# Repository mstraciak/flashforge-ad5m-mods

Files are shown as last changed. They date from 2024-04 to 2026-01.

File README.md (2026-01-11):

# flashforge-ad5m-mods

Here are my mods for flashforge adventurer 5m.
1) 3D chameleon files for FF Ad5M
2) Happy Turtle Lettuce Feeder with 3D chameleon board- HTLF for ANY 3D printer! (also on [printables](https://www.printables.com/model/1534632-htlf-with-3d-chameleon-pcb) ) 
3) Simple magnetic mount for LED bar
4) Change origin of the buildplate (X0,Y0) to the front left corner.
5) Extruder housing. If you have broken or just need new housing, try my design. (recomend printing with SLA printer) 
6) Start/end gcode with autoleveling at the begining of the print for orcaslicer 2.0.0.dev (usefull with sending files over wifi)  
7) Connecting ANY usb webcam direct do LCD (not with existing USB port)
8) Web control printer on local web server. (working with stock 2.4.5 firmware) **I highly recommend a better version of my webcontrol from [Andy4Shurr](https://github.com/Andy4Shurr/flashforge-ad5m-mods)**

This and other useful mods for flashforge adventurer 5m/5m pro are [here](https://github.com/g992/flashforge-ad5m-5mpro-research).

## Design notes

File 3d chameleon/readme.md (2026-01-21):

# Files for 3D chameleon on Flashforge Adventurer 5M

## My STL files for using chameleon

**chameleon-*.stl:**\
Print from PETG. part with oled mount print facing down, support only on buildplate.

 Position of switch is in the middle on the left side. 

## Firmware files
All collected firmware files for 3D chameleon. I recommended version MK4.1. Also is here guide to burn firmware.

## Files for servo cutter and for manual cutter

## Filament semi-automatic cutter
cutter for the filament is [here](https://www.printables.com/model/1252462-update-semi-automatic-filament-cutter-for-flashfor)

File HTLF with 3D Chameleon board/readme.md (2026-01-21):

# Files for modified HTLF with 3d chameleon PCB

**Changes in HTLF design (new STL files):**
- The lobe elements are rotated 70 degrees relative to each other. This ensures that only one filament is pressed at a time and the others are loose.
- The PCB holder is supplemented with holes for the 3D chameleon PCB.
- Only the home switch is used. The other switches are not used.

**Changes in firmware:**
- Removed OLED display support (due to ws2812b and home switch support)
- Home switch connected to the connector marked "S LIMIT"
- WS2812B connected to the connector marked "FILAMENT"
- Removed the option to choose a random filament
- Removed the option to select the next filament in the sequence
- Removed "no command" option. Replaced with "home and idle" command
- Removed motor vibration function when selecting filament
- Removed support for other devices
- Option to select extruder feedrate in code (1197,1496,1796,2245). Note: Original 3D chameleon uses feedrate 1500, so the setting for feedrate 1496 can be used).
- After inserting the current filament into the extruder, the lobe elements move to a parking position where they do not press any filament.
- Changed home and unload command: process move (unload-home/home and go to parking position)
**The "guillotine" function for cutting filament using a servo motor is untouched.**

**Planned changes:**
- Code optimization

cutter for the filament is [here](https://www.printables.com/model/1252462-update-semi-automatic-filament-cutter-for-flashfor)

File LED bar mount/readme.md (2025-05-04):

# Magnetic LED mount

Magnetic mount for selfsticking LED bar.
Its suitable for round magnets 5x1mm.

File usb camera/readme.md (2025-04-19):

# flashforge-ad5m-mods

How to connect any usb camera to camera port on LCD:
1) on LCD is camera port as "USB_CAMERA" and mark +5V, N (neative data), P (positive data), GND.
2) make short cable with connector for port on LCD and USB-A female. If you need a connector, buy a 5 pin JST PH 2.0mm female
3) just connect any usb camera to this new usb port and enable it on LCD.
   now you can use camera and usb stick at the same time.
   




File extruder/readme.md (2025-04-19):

# Files for extruder housing.
i try make model of extruder housing for my printer, because original was damaged with unclog tool. THIS MODEL IS UNTESTED, so if anyone send me feedback, i will be glad for that. original back plate should be fit to this.
Always use latest version. Older versions are only for reference and backup.

**Printing info (SLA):**

Printer: Anycubic photon (with mono upgrade from chitu)

Slicer: Chitubox Basic 2.3

Profile: Elegoo Mars 2 Pro, changed exposure time from 2.5s to 1.7s for accuracy

Resin: Creality Standard Resin

Be sure your SLA printer is calibrated for accuracy.

**Assembly notes:**

Use all parts from original extruder include screw for tension.

M3 threads for tension screw and fan must be tapped.

For fan use M3x16 screws with flat head, or use original screw (not needed tapped).

**Update 19.4.2025** - v4 - its fully function and its tested (load/unload filament) successfully, still untested in printing. still need small correction but now it is usable





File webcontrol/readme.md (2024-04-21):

it need apache+php (like xampp), enabled socket module in php.ini. copy files (index.php and ff.php) to html folder and just open in browser:
>http://localhost/<path_to_files>/index.php?ip=<IP_PRINTER>

its simple, code need correction (i know, i am beginer). 
you can check temperature, progres of printing, webcam, and turn LED ON/OFF, pause, resume, cancel, home.

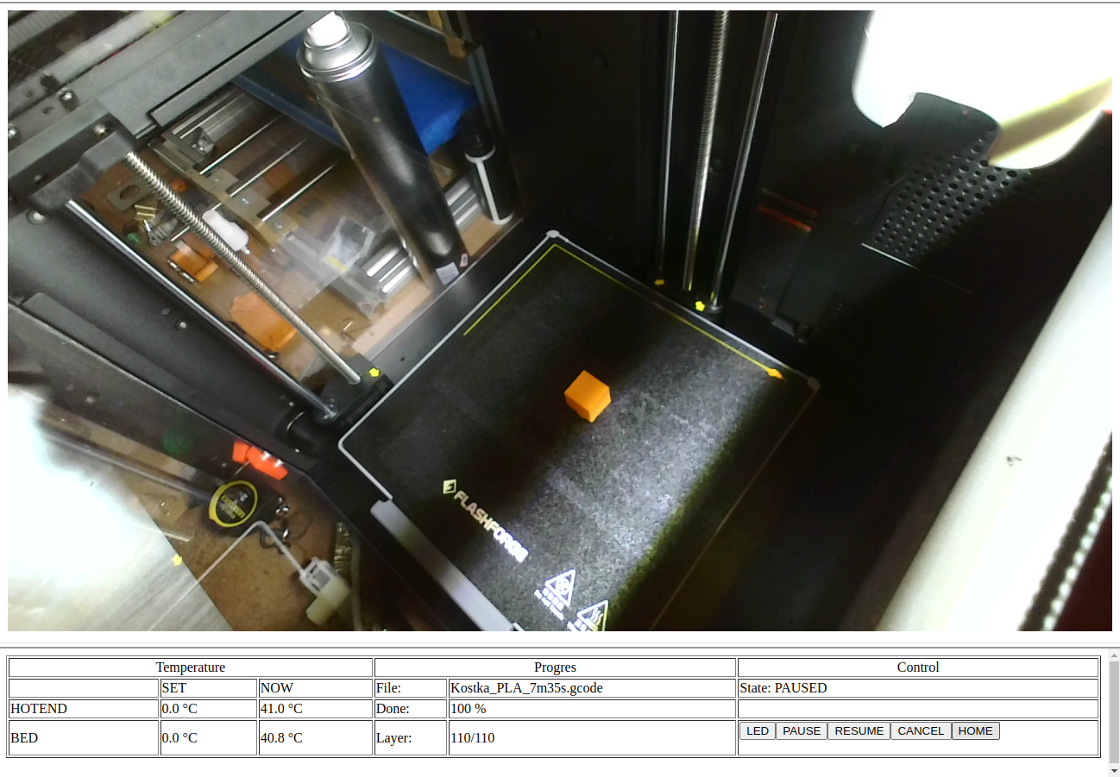
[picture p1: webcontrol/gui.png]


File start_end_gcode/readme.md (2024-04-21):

This start gcode makes auto bed mesh leveling before print. 

start.gcode is my version of start gcode for leveling before print.

start2.gcode is similiar like factory process of leveling before print.

Its usefull when you sending files over wifi directly from OrcaSlicer 2.0.0dev [(thanks to iherbak)](https://github.com/iherbak/OrcaSlicer) and want leveling before print.

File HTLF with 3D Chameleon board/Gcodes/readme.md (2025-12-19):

## My own g-codes for start, end and filament change. 
## You can get inspired by my g-codes.

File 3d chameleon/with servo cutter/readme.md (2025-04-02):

# Files for 3D chameleon on Flashforge Adventurer 5M with servo cutter (autoclipy)
## Gcodes for Flashforge adventurer 5M
### Start gcode:
- Cleaning nozzle before leveling
- Leveling heatbed
- Purge filament from previous printing (if there is something forgetten)
- Select color by orca slicer (if you chose different color for start printing than #1, it will auto select correct color)
- Load filament into extruder
- Purge nozzle before printing

### End gcode:
- Select "Unload filament" command in chameleon
- Cut filament
- Purge filament from printing (prepare for load in new printing)
- Homing
- Beep for notification of ended printing

### Change gcode:
- Retract filament for cutting (to minimize residual filament = less filaments for clean color)
- Select correct color
- Cut filament
- Unload filament
- Extrude residual filament (prepare extruder for new color)
- Load new color

Note: With my gcodes was flushing volumes between each filament 215mm<sup>3</sup> (Multiplier 1.00). Its good value for start.
  
## My STL files for using chameleon
**ad5m-v5-4in1.stl:**\
Rotate with holes to buildplate. support only on buildplate.

**chameleon-*.stl:**\
Print from PETG. part with oled mount print facing down, support only on buildplate.

**clipy-ad5m-body.stl:**\
Rotate to the flat side. need all supports.
 Position of switch is in the middle on the left side. 

## Firmware files.
All collected firmware files for 3D chameleon. I recommended version MK4.1. Also is here guide to burn firmware.

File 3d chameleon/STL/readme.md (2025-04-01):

**4tubes - guider.stl:**\
Simple holder for 4 tubes.

**chameleon-*.stl:**\
Print from PETG. part with oled mount print facing down, support only on buildplate.

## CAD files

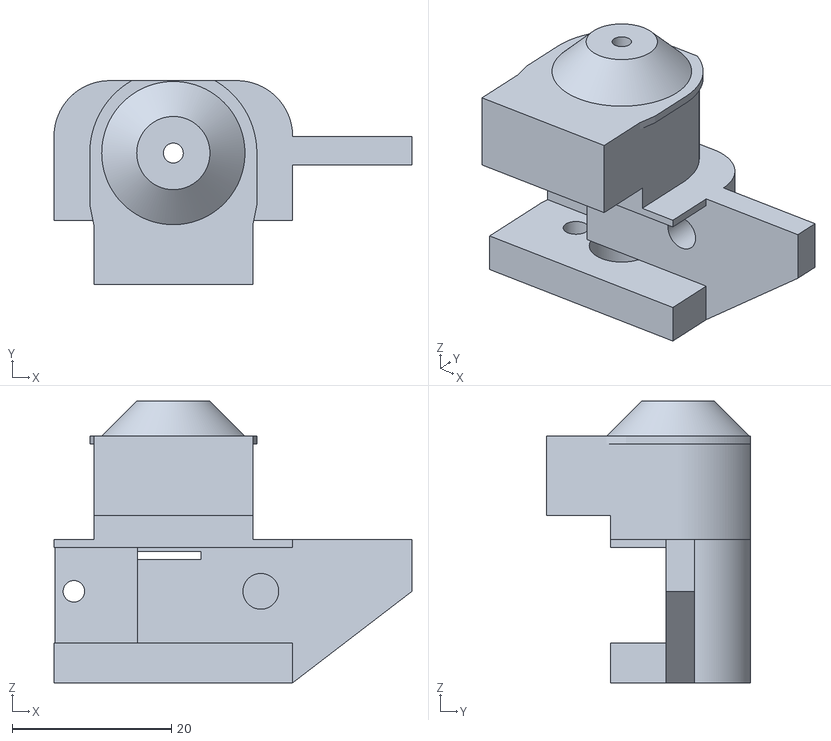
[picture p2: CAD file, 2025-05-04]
3d chameleon/manual cutter/STL/ad5m cut - 1to1input.v2.orientation.stl
45.0 x 25.6 x 35.4

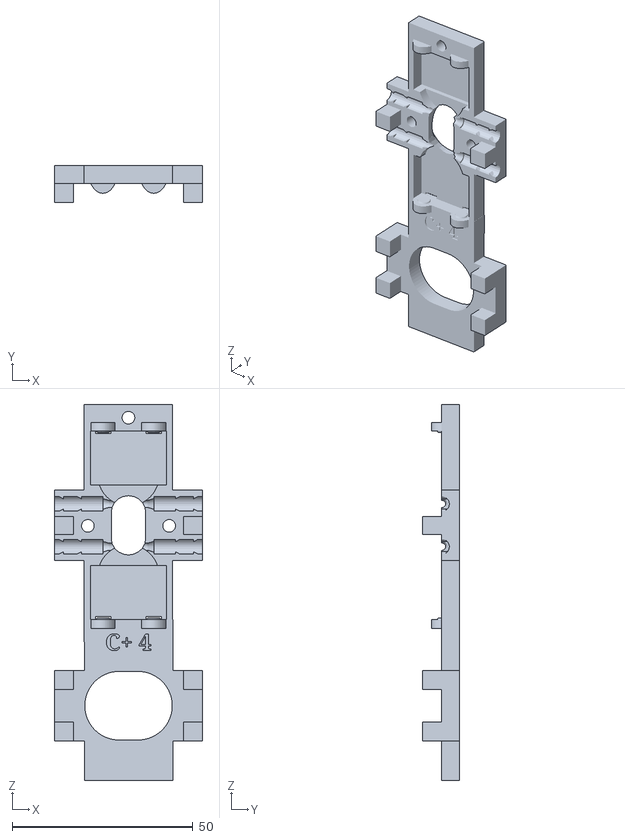
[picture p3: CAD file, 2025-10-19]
3d chameleon/STL/3DChameleon 4.0 (C Part) - v2.stl
41.0 x 10.2 x 104.1

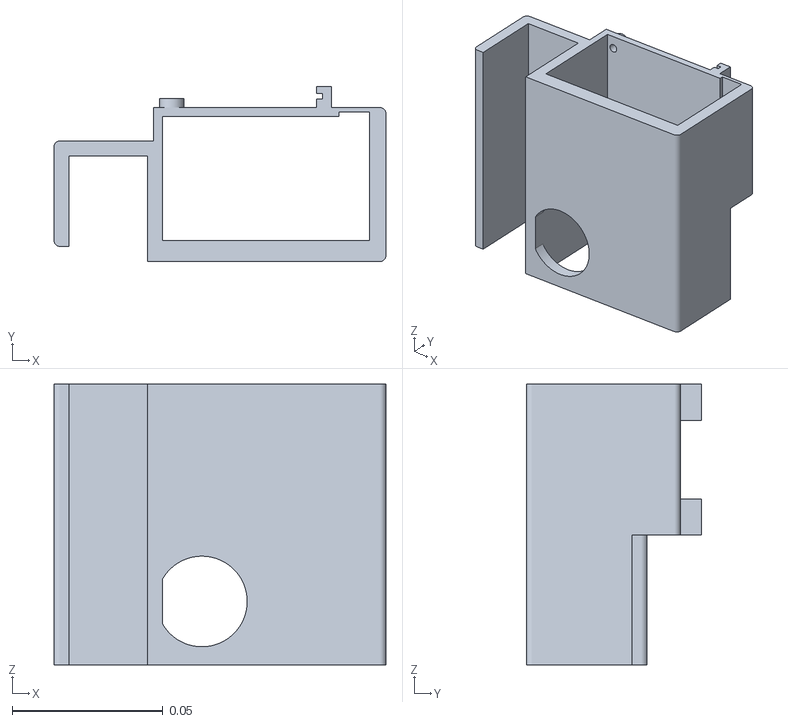
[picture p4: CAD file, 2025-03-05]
3d chameleon/with servo cutter/STL/chameleon-drziak.stl
0.11 x 0.058 x 0.093

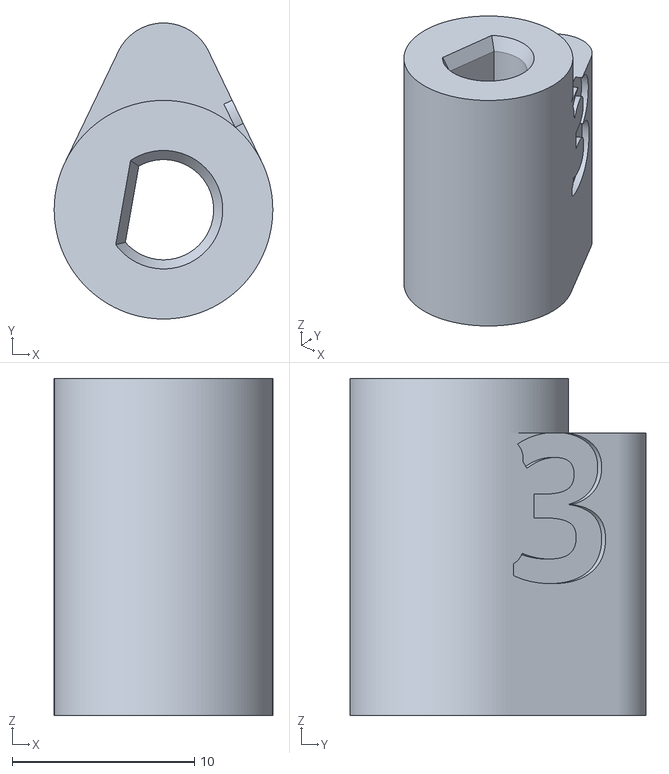
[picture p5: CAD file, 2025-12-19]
HTLF with 3D Chameleon board/STLs/lobe-70dg - Part 3.stl
12.0 x 16.2 x 18.5

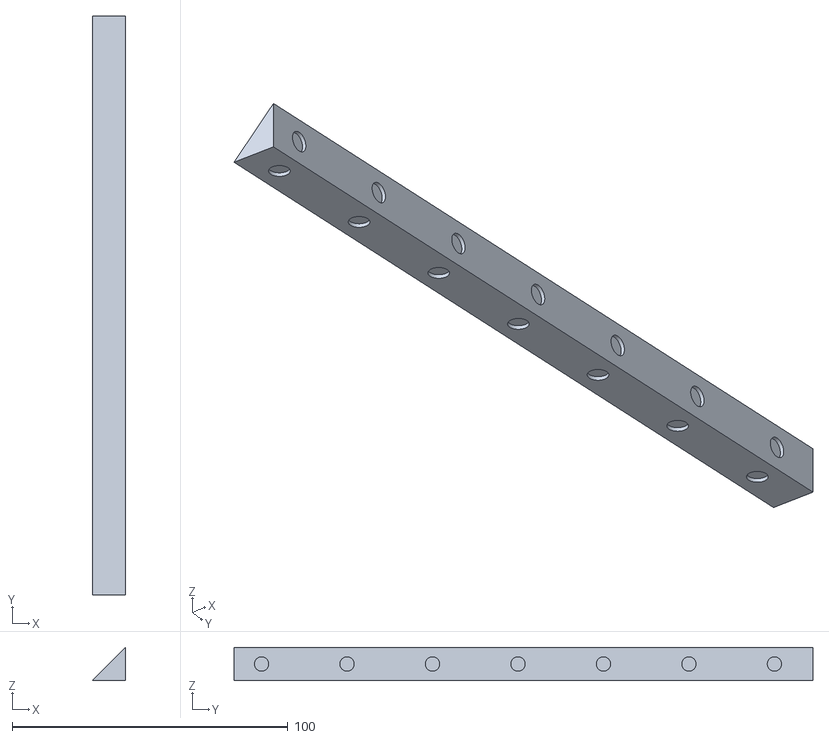
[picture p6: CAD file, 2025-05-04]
LED bar mount/LED - mount.stl
12.0 x 210.0 x 12.0

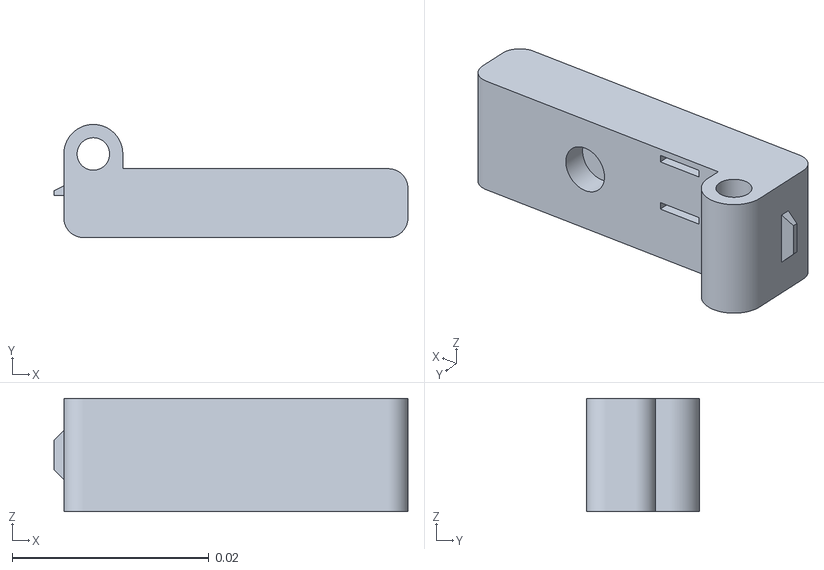
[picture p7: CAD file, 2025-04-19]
3d chameleon/manual cutter/STL/ad5m cut - arm.v2.stl
0.036 x 0.0115 x 0.0115

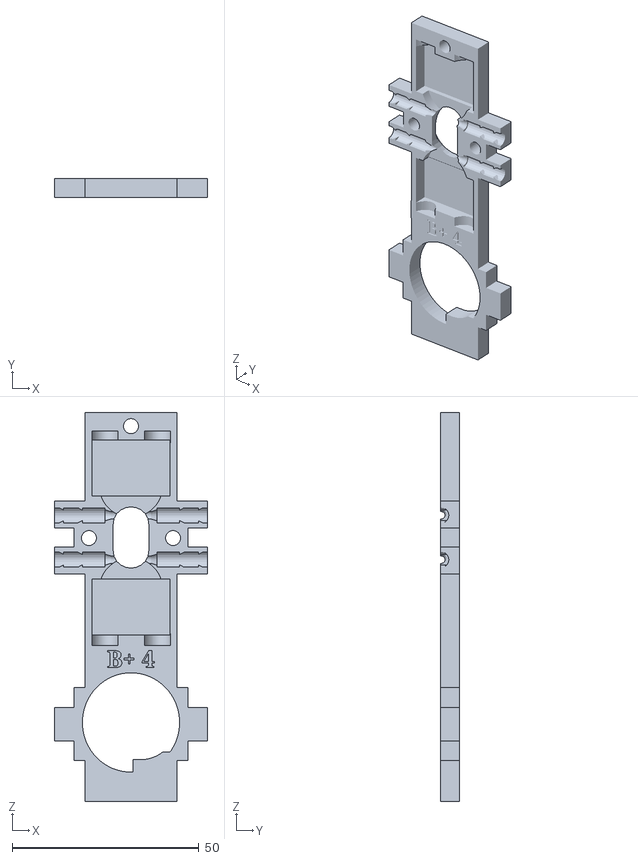
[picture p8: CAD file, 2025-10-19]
3d chameleon/STL/3DChameleon 4.0 (B Part) - v2.stl
41.0 x 5.00 x 104.1

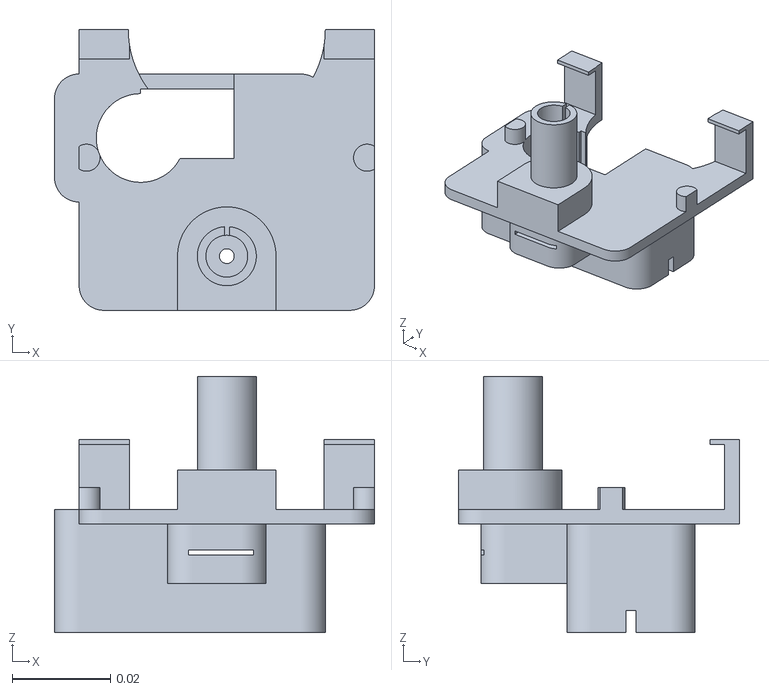
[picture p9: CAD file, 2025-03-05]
3d chameleon/with servo cutter/STL/clipy-ad5m-body.stl
0.065 x 0.057 x 0.052

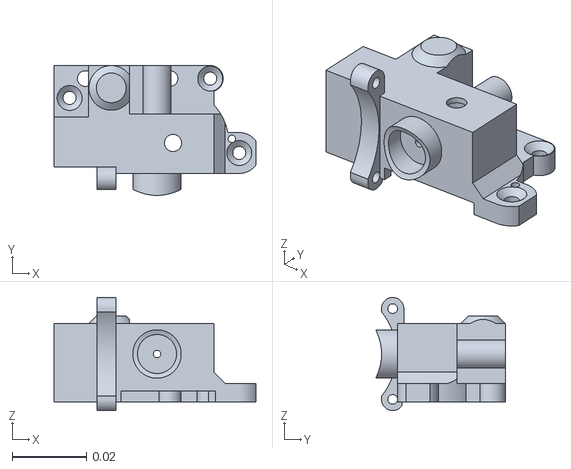
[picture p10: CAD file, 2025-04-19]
extruder/ad5m - extruder.v4.stl
0.0543 x 0.0349 x 0.0304

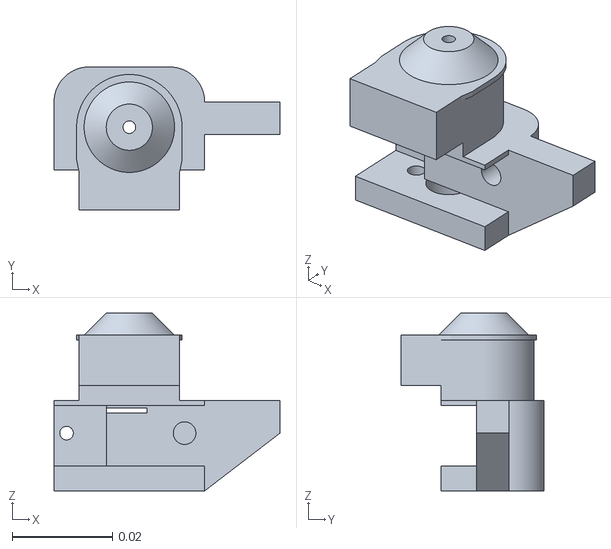
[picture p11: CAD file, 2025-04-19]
3d chameleon/manual cutter/STL/ad5m cut - 1to1input.v2.stl
0.045 x 0.0285 x 0.0354

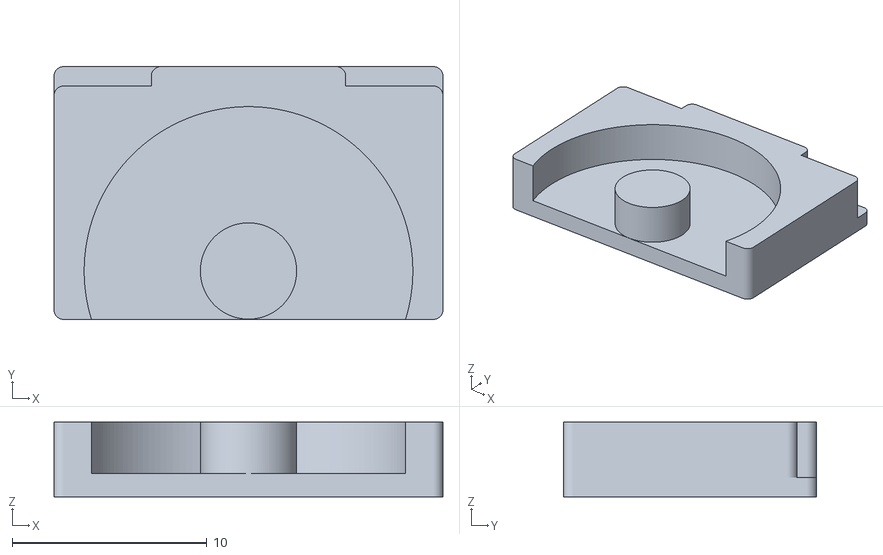
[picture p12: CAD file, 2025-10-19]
3d chameleon/STL/bearing - carriage.stl
20.0 x 13.0 x 3.85

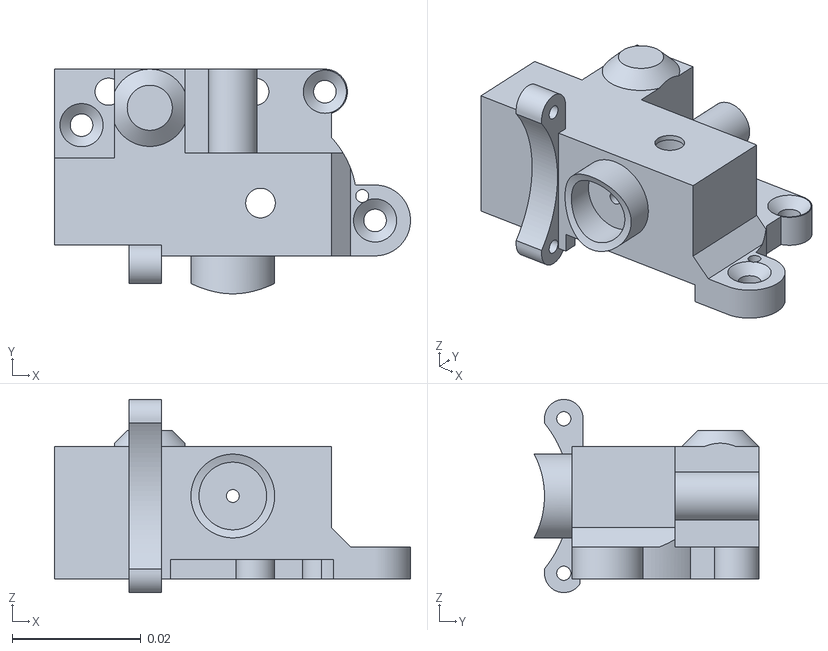
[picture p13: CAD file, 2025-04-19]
extruder/ad5m - extruder.stl
0.0553 x 0.0349 x 0.03

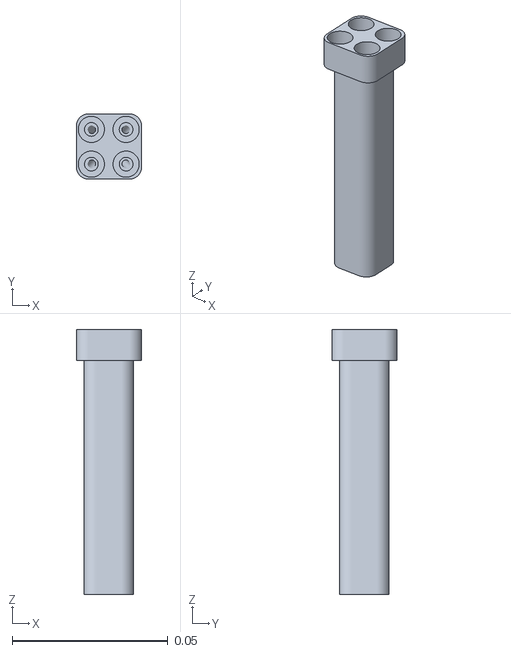
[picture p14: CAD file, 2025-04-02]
3d chameleon/manual cutter/STL/ad5m 4n1 - body.stl
0.021 x 0.021 x 0.085

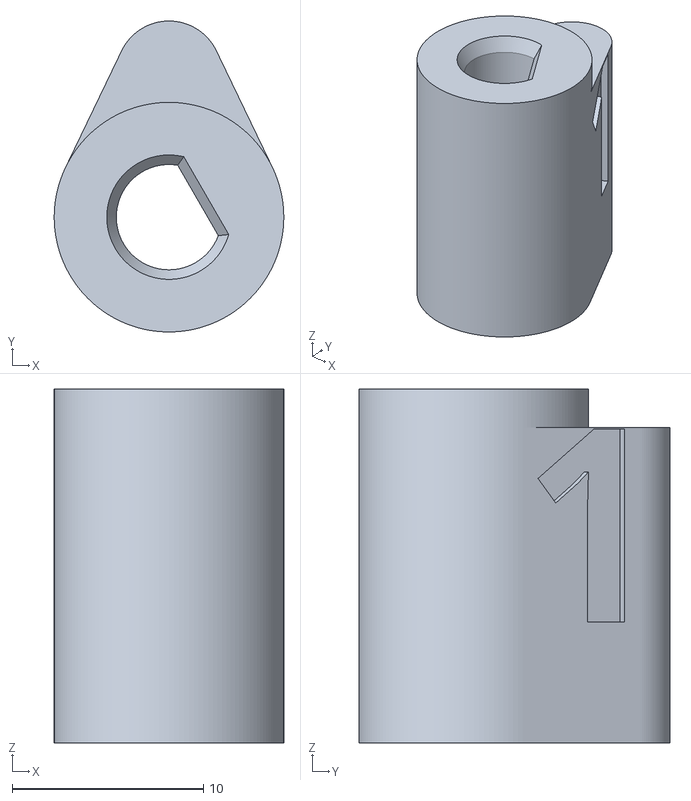
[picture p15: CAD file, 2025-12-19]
HTLF with 3D Chameleon board/STLs/lobe-70dg - Part 1.stl
12.0 x 16.2 x 18.5

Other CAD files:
HTLF with 3D Chameleon board/STLs/lobe-70dg - Part 4.stl
3d chameleon/with servo cutter/STL/ad5m-v5-4in1.stl
HTLF with 3D Chameleon board/STLs/lobe-70dg - Part 2.stl
3d chameleon/STL/3DChameleon 4.0 (B Part) RESIN - v2.stl
3d chameleon/STL/4tubes - guider.stl
3d chameleon/STL/chameleon-krytka.stl
3d chameleon/STL/chameleon-krytkaoled13.stl
3d chameleon/manual cutter/STL/ad5m cut - 1to1input.stl
3d chameleon/manual cutter/STL/ad5m cut - arm - long.stl
3d chameleon/manual cutter/STL/ad5m cut - arm - middle.stl
3d chameleon/manual cutter/STL/ad5m cut - arm -short.stl
3d chameleon/manual cutter/STL/ad5m cut - block.stl
HTLF with 3D Chameleon board/STLs/board_mount - chameleon.stl
extruder/ad5m - extruder-v3.stl
extruder/ad5m - extruder.v2.stl

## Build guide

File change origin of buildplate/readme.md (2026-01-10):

After installing klipper_mod (from xblax) is origin (X0,Y0) at the center of the buildplate. Homing position is X110 and Y110.
Here are steps, if you need origin in the front left corner (X0,Y0) and homing position at X220, Y220. 
Steps here are for klipper_mod v00.06 beta.
Here are lines from my config files.

## Changes in printer.base.cfg:
> [!NOTE]
>Old values begining with #.
>Example: ``` position_endstop: 220 #110```  (110 is old value-commented, 220 is new value)

1. change in [stepper_x]
   ```
   position_endstop: 220 #110
   position_max: 220.2 #110.1
   position_min: 0 #-110
   ```
2. change in [stepper_y]
   ```
   position_endstop: 220 #110
   position_max: 220.2 #110.1
   position_min: 0 #-110
   ```

3. change in [resonance_tester]
   ```
   probe_points:
       110,110,100 #0,0,100
   ```

4. change in [homing_override]
   ```
   #G1 X105 Y105 Z210 F1800
   G1 X215 Y215 Z210 F1800
   ```
5. change in [bed_mesh]
    ```
   mesh_min: 10, 10 #-100, -100            
   mesh_max: 210, 210 #100, 100
    ```

6. change in [screw_tilt_adjust]
    ```
   screw1: 16, 16 #-94, -94
   screw1_name: Left Near
   screw2: 204, 16 #94, -94
   screw2_name: Right Near
   screw3: 204, 204 #94, 94
   screw3_name: Right Far
   screw4: 16, 204 #-94, 94
    ```

## Changes in printer.cfg:
1. there is normaly no changes

## Changes in macros.cfg (note: i dont have PRO version):
> [!NOTE]
>Old values begining with ;
> Example: ```variable_custom_park_x    : 110 ;-105.0 ``` (-105 is old value-commented, 110 is new value)

1. change in [gcode_macro _CLIENT_VARIABLE]
   ```
   variable_custom_park_x    : 110 ;-105.0  ; custom x position; value must be within your defined min and max of X
   variable_custom_park_y    : 10 ;-105.0  ; custom y position; value must be within your defined min and max of Y
   variable_park_at_cancel_x : 110 ;105     ; different park position during CANCEL_PRINT [None/Position as Float]; park_at_cancel must be True
   variable_park_at_cancel_y : 10 ;105     ; different park position during CANCEL_PRINT [None/Position as Float]; park_at_cancel must be True
   ```
   
2. change in [gcode_macro _COMMON_END_PRINT]
   ```
   ;G1 X105 Y105 Z220 F1500 ; move near end stop position
    G1 X215 Y215 Z220 F1500 ; move near end stop position
   ```

3. change in [gcode_macro _PRIME_NOZZLE]
   ```
    ;G90
    ;M83
    ;G1 E-1.5 F800
    ;G1 X110 Y-110 F6000
    ;G1 E2 F800
    ;G1 Y-110 X55 Z0.25 F4800
    ;G1 X-55 E8 F2400
    ;G1 Y-109.6 F2400
    ;G1 X55 E5 F2400
    ;G1 Y-110 X55 Z0.45 F4800
    ;G1 X-55 E8 F2400
    ;G1 Y-109.6 F2400
    ;G1 X55 E5 F2400
    ;G92 E0

    G90
    M83
    G1 E-1.5 F800
    G1 X220 Y0 F6000
    G1 E2 F800
    G1 Y0 X165 Z0.25 F4800
    G1 X55 E8 F2400
    G1 Y0.4 F2400
    G1 X165 E5 F2400
    G1 Y0 X165 Z0.45 F4800
    G1 X55 E8 F2400
    G1 Y0.4 F2400
    G1 X165 E5 F2400
    G92 E0

## Changes in OrcaSlicer:
1. open settings for your printer profile
   ![img](img/orca_orgin1.png)

2. Select "set" for printable area
   
   ![img](img/orca_origin2.png)
3. Change "origin" coordinates to X0 and Y0.

   ![img](img/orca_origin3.png)

> [!CAUTION]
> Dont forget change your start/end gcodes!!!

And now you should have origin in left front corner of the buildplate and you can use exclude area and primetower location where you want.

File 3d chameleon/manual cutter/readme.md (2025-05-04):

# Files for 3D chameleon on Flashforge Adventurer 5M <ins>WITHOUT</ins> servo cutter (manual or semi-automatic cutting)
## Gcodes for Flashforge adventurer 5M
### Start gcode:
- Cleaning nozzle before leveling
- Leveling heatbed
- Purge filament from previous printing (if there is something forgetten)
- Select color by slicer (if you chose different color for start printing than #1, it will auto select correct color)
- Load filament into extruder
- Purge nozzle before printing

### End gcode:
- Select "Unload filament" command in chameleon
- Move to position and cut filament
- Purge filament from printing (prepare for load in new printing)
- Homing
- Beep for notification of ended printing

### Change gcode:
- Retract filament for cutting (to minimize residual filament = less filaments for clean color)
- Select correct color
- Move to position and cut filament
- Unload filament
- Extrude residual filament (prepare extruder for new color)
- Load new color

Note: With my gcodes was flushing volumes between each filament 215mm<sup>3</sup> (Multiplier 1.00). Its good value for start.

## My STL files for using chameleon
**ad5m cut-arm-*.stl:**\
Cutting arm for manual cutter. Print without support.

**ad5m cut-block.stl:**\
Block for manual cutting. Position is front left corner.

**ad5m cut-1to1input.stl:**\
Main body for manual cutter. Print with support. After printing clean all holes, specialy for knife.

**4tubes - guider.stl:**\
Simple holder for 4 tubes.

**ad5m 4n1 - body.stl:**\
4 in 1 ptfe adapter for using festo fittings. Alternatively you can use bambulab 4to1 ptfe adapter.

**UPDATE 19.4.2025**
Recomend using version 2 where is knife position lower 5mm (closer to the hotend) 

**UPDATE 4.5.2025**
Added version with better orientation. since this version i use bambulab filament hub 4to1 and ver.2 gcodes (start, end, change).
Added gcode to existing macro in file macros.cfg. For cutting and unload filament with cancel printing.

**Other parts:**
- one piece from 9mm blade for utility knife
- spring from ball pen
- M3x20 
- M3x16 (as stop screw) 
- push-in fitting from festo for 4mm tube

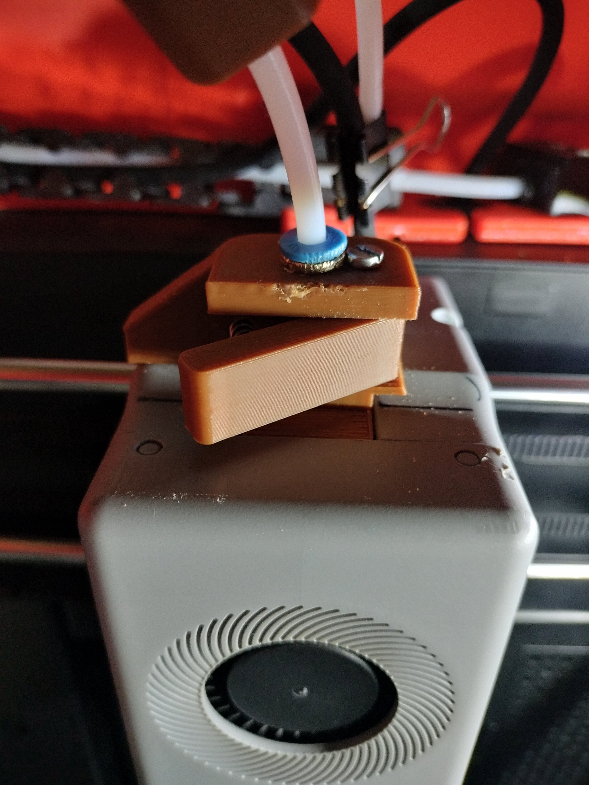
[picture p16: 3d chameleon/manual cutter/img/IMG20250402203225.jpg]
  
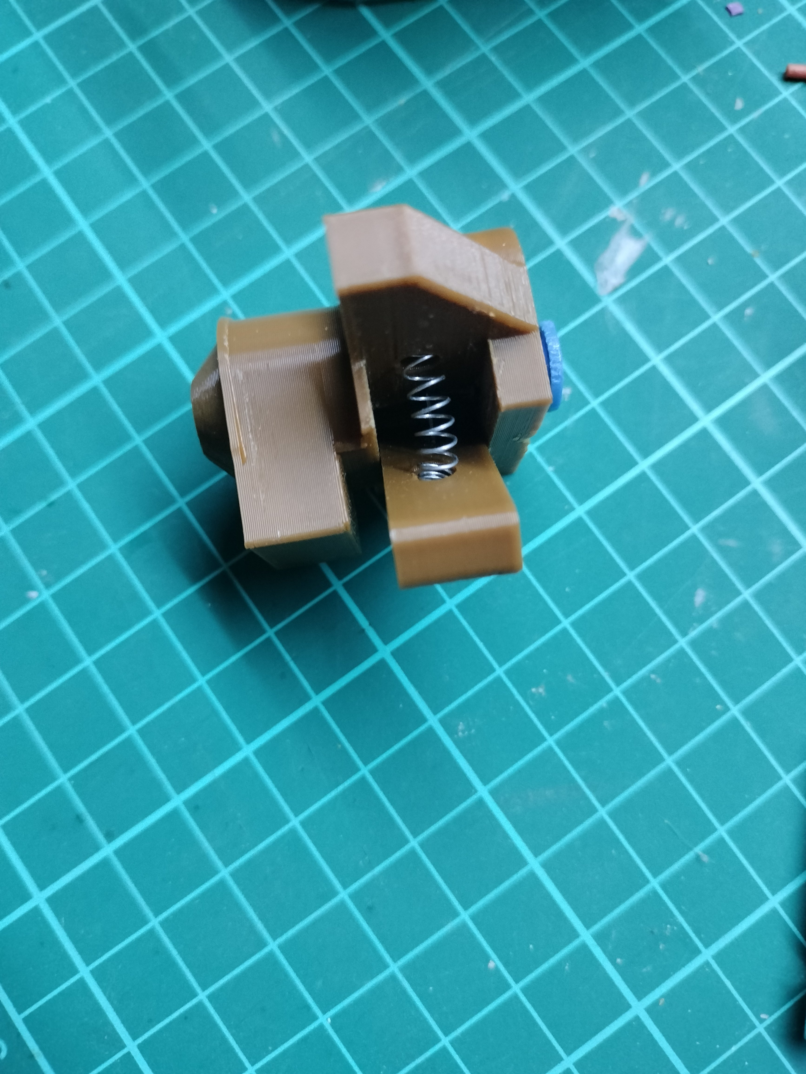
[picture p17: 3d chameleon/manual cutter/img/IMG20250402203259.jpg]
    
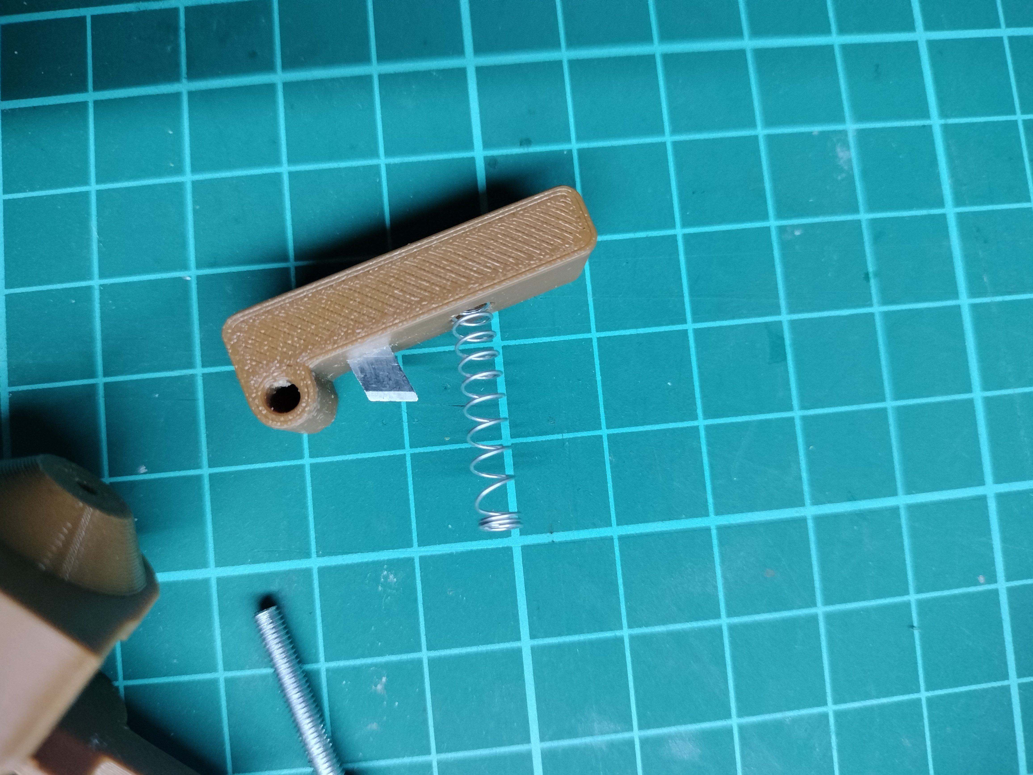
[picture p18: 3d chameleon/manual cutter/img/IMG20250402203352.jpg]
    
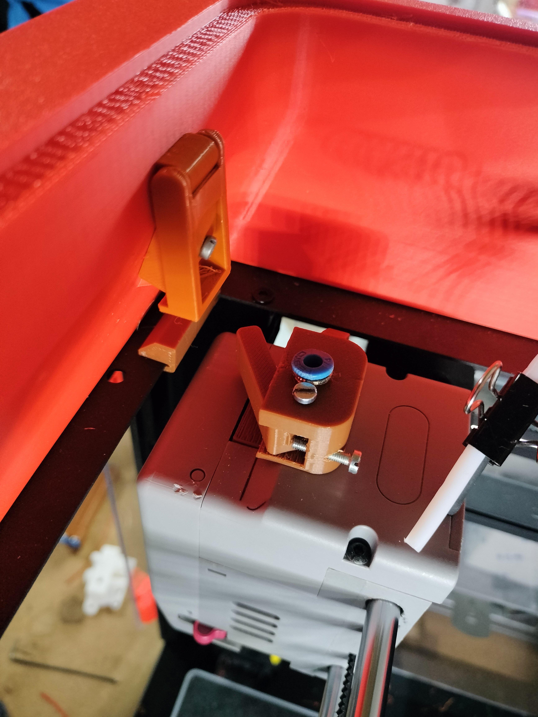
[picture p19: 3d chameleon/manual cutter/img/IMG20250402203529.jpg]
    
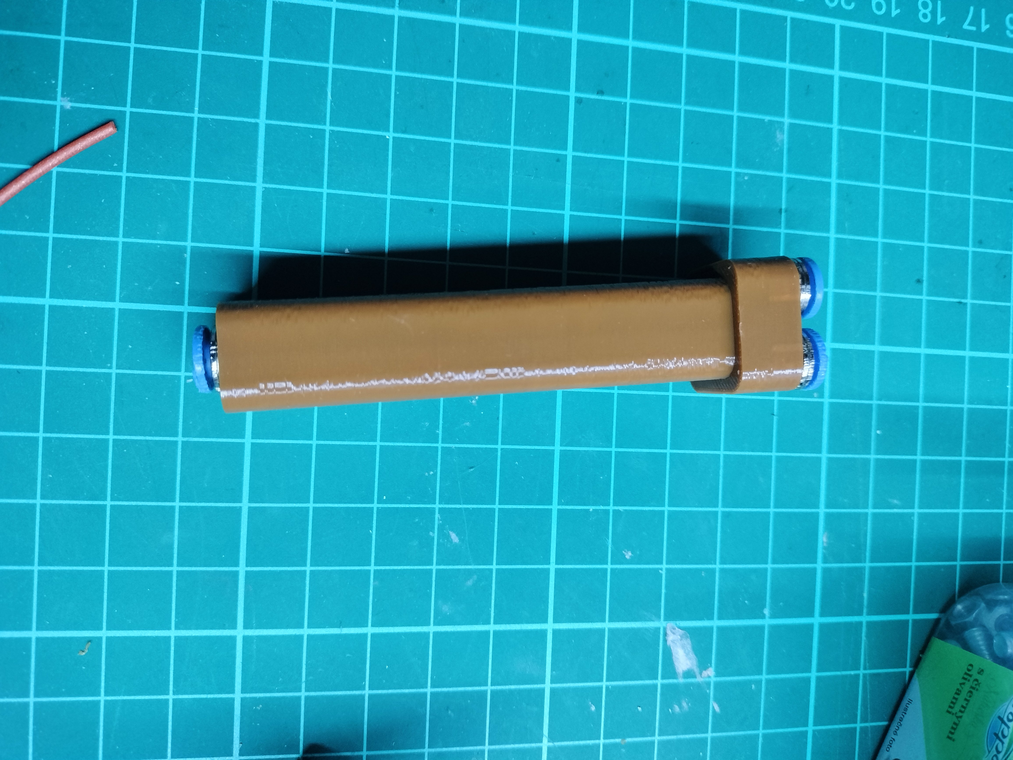
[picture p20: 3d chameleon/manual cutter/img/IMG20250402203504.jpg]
    
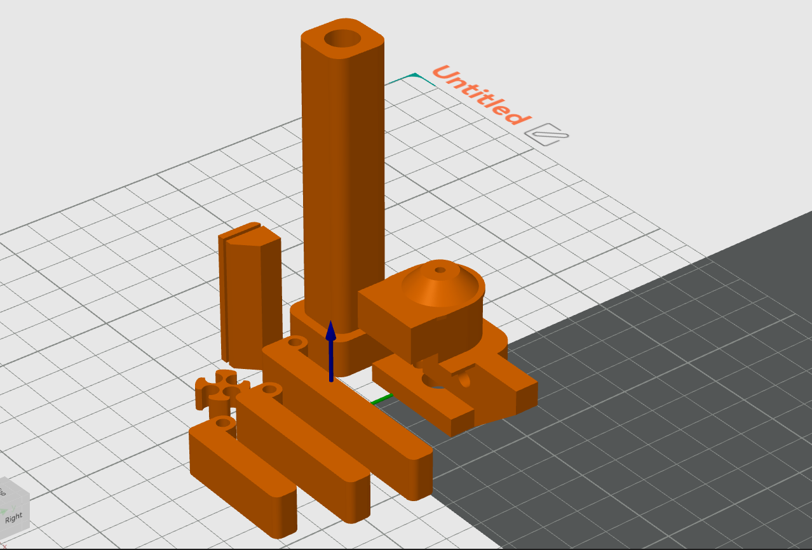
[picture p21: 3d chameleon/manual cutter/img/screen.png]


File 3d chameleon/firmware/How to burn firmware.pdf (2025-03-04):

## Burning 3D Chameleon Firmware using Arduino Uno on Windows

### Load Arduino Uno with ArduinoISP

1. Plug in my Arduino Uno (clone) via USB.
2. Startup Arduino IDE (mine is version 1.8.19)
3. Made sure my Arduino Uno and port is selected

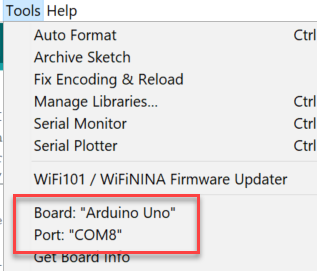
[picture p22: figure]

Remember the port number as we’ll need this for avrdude later. Mine is com8

4. Open the ArduinoISP sketch that is provided with the IDE. Go to File → Examples →> 11. ArduinoISP→ArduinoISP

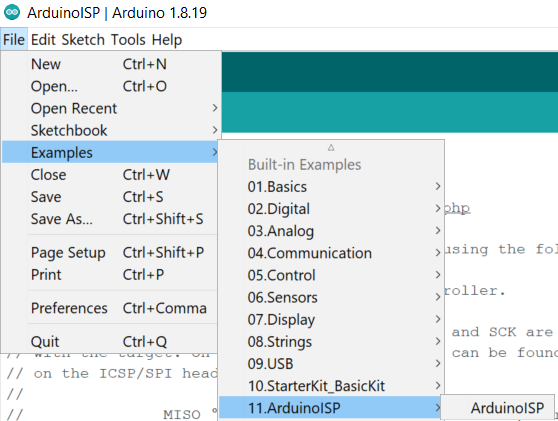
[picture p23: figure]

5. Upload the Sketch to UNO , Sketch → Upload. It’ll compile and upload to UNO
6. Unplug the UNO

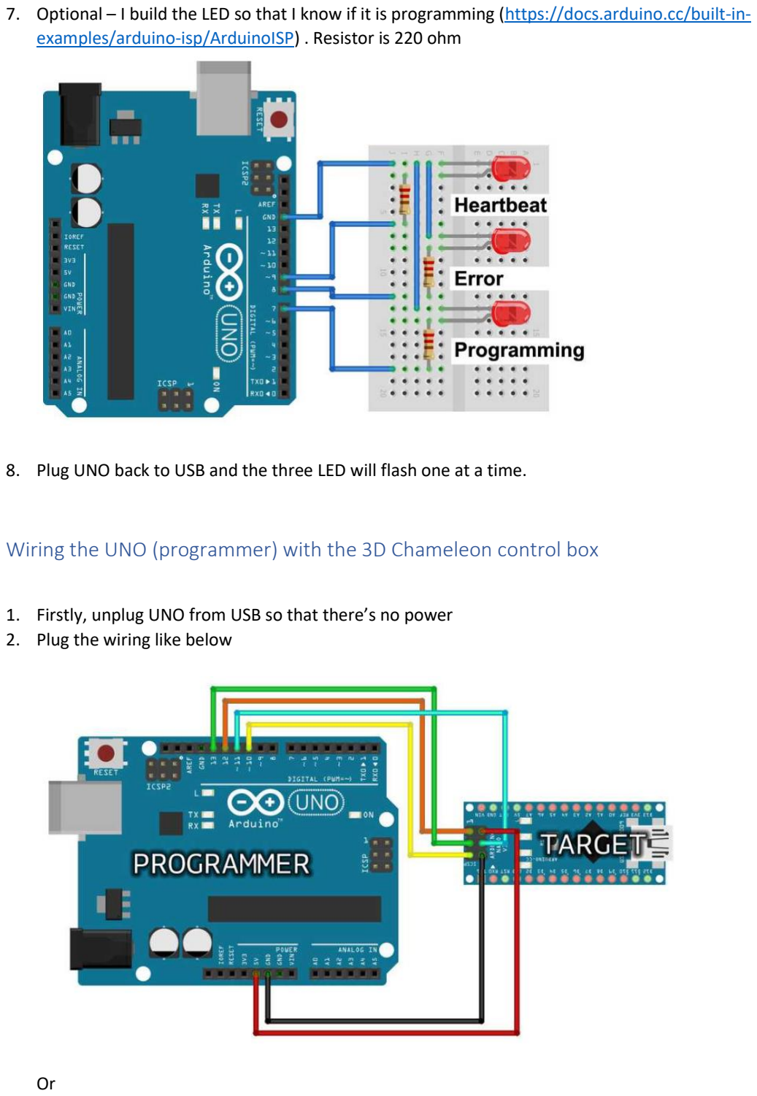
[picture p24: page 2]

7. Optional – I build the LED so that I know if it is programming (https://docs.arduino.cc/built-inexamples/arduino-isp/ArduinoISP) (https://docs.arduino.cc/built-in-examples/arduino-isp/ArduinoISP) . Resistor is 220 ohm
8. Plug UNO back to USB and the three LED will flash one at a time.

### Wiring the UNO (programmer) with the 3D Chameleon control box

1. Firstly, unplug UNO from USB so that there’s no power
2. Plug the wiring like below

Or

| Arduino as ISP | 3D Chameleon ICSP pin
MISO | D12 | 1
Vcc / 5V | 5V | 2
SCK | D13 | 3
MOSI | D11 | 4
RESET | D10 | 5
GND | GND | 6
3. Pin 1 of 3d Chameleon ICSP board is under the ‘I’

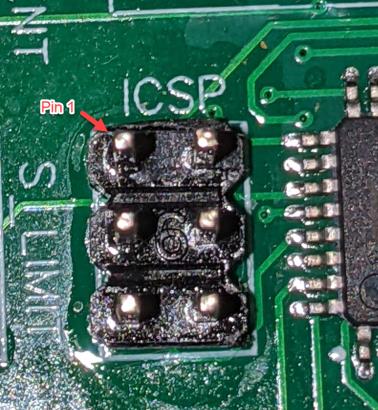
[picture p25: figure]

4. My final wiring looks like this

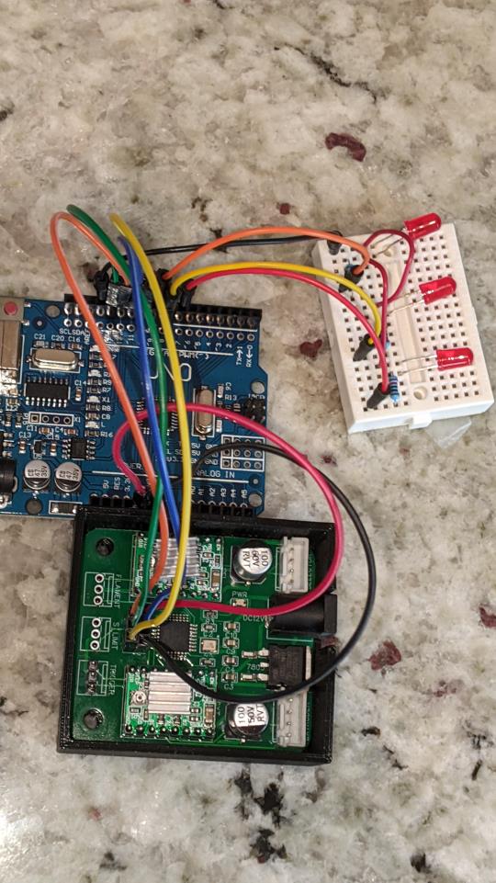
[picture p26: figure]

5. Now it’s ready for programming

### Flashing the Firmware using avrdude command prompt

1. Download the new firmware. I put it where the avrdude config file (avrdude.conf) is because I don’t want to type long parameters. In my case I put it in
C:\MyDev\arduino-1.8.19\hardware\tools\avr\etc
2. Start the command prompt

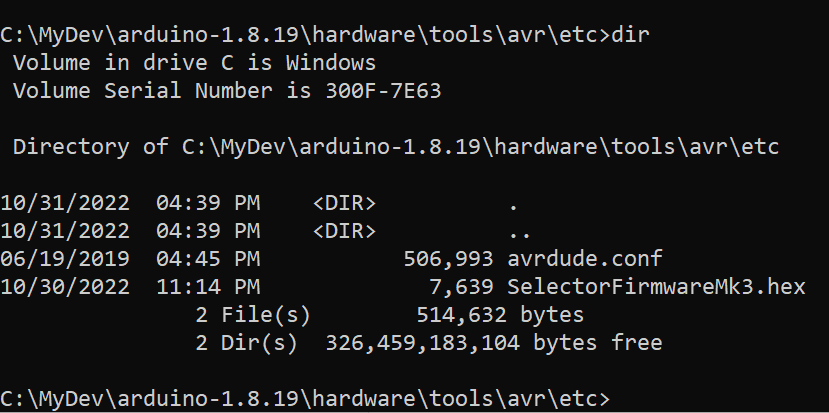
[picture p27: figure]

3. I added the location of the avrdude executable to my path

Path= path=C:\MyDev\arduino-1.8.19\hardware\tools\avr\bin;%path%

Now I can call avrdude from the config file location.

4. Plug in the UNO back to the USB port and wait for it to powerup.
5. Then I check to see if UNO can talk to the 3D Chameleon with this command. Fyi my comm port to the UNO is com8.

avrdude -P com8 -b 19200 -c avrisp -p m328p -v

6. If it works ok, it will not have errors , eg:

C:\MyDev\arduino-1.8.19\hardware\tools\avr\etc>avrdude -P com8 -b 19200 -c avrisp -p m328p -v

avrdude: Version 6.3-20190619
Copyright (c) 2000-2005 Brian Dean, http://www.bdmicro.com/
Copyright (c) 2007-2014 Joerg Wunsch

System wide configuration file is "C:\MyDev\arduino-1.8.19\hardware\tools\avr\etc\avrdude.conf"

Using Port | : com8
Using Programmer | : avrisp
Overriding Baud Rate | : 19200
AVR Part | : ATmega328P

Chip Erase delay | : 9000 us
PAGEL | : PD7
BS2 | : PC2
RESET disposition | : dedicated
RETRY pulse | : SCK
serial program mode | : yes
parallel program mode | : yes
Timeout | : 200
StabDelay | : 100
CmdexeDelay | : 25
SyncLoops | : 32
ByteDelay | : 0
PollIndex | : 3
PollValue | : 0x53
Memory Detail | :
Block Poll | Page | Polled
Memory Type Mode Delay Size Indx Paged Size Size #Pages MinW MaxW ReadBack ----------- ---- ----- ----- ---- ------ ------ ---- ------ ----- ----- ---------
eeprom | 65 20 4 0 no | 1024 4 | 0 3600 3600 0xff 0xff
flash | 65 6 128 0 yes 32768 128 256 4500 4500 0xff 0xff
lfuse | 0 0 0 0 no | 1 0 | 0 4500 4500 0x00 0x00
hfuse | 0 0 0 0 no | 1 0 | 0 4500 4500 0x00 0x00
efuse | 0 0 0 0 no | 1 0 | 0 4500 4500 0x00 0x00
lock | 0 0 0 0 no | 1 0 | 0 4500 4500 0x00 0x00
calibration 0 0 0 0 no | 1 0 | 0 0 0 0x00 0x00
signature | 0 0 0 0 no | 3 0 | 0 0 0 0x00 0x00

Programmer Type : STK500
Description : Atmel AVR ISP
Hardware Version: 2
Firmware Version: 1.18
Topcard | : Unknown
Vtarget | : 0.0 V
Varef | : 0.0 V
Oscillator | : Off
SCK period | : 0.1 us

avrdude: AVR device initialized and ready to accept instructions

Reading | ################################################## | 100% 0.03s

avrdude: Device signature = 0x1e950f (probably m328p)
avrdude: safemode: lfuse reads as 62 avrdude: safemode: hfuse reads as D9 avrdude: safemode: efuse reads as FF

avrdude: safemode: lfuse reads as 62 avrdude: safemode: hfuse reads as D9 avrdude: safemode: efuse reads as FF avrdude: safemode: Fuses OK (E:FF, H:D9, L:62)

avrdude done. Thank you.

7. Now I burn the firmware using this command and if there are no errors, then it is done. Make sure at the end of the hex file there is a :i (colon ‘i’) for intel code.

avrdude -P com8 -b 19200 -c avrisp -p m328p -v -e -U flash:w:SelectorFirmwareMK3.hex:i

8. Notice: Don’t change any fuse settings when programming.

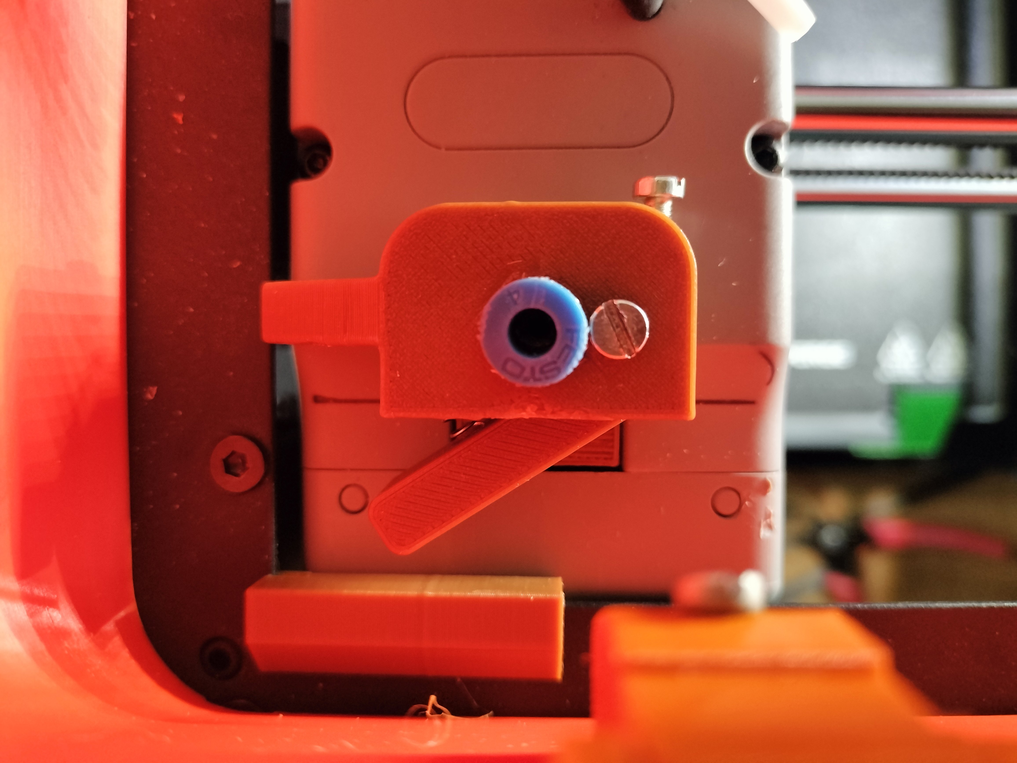
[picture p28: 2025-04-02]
3d chameleon/manual cutter/img/IMG20250402203559.jpg

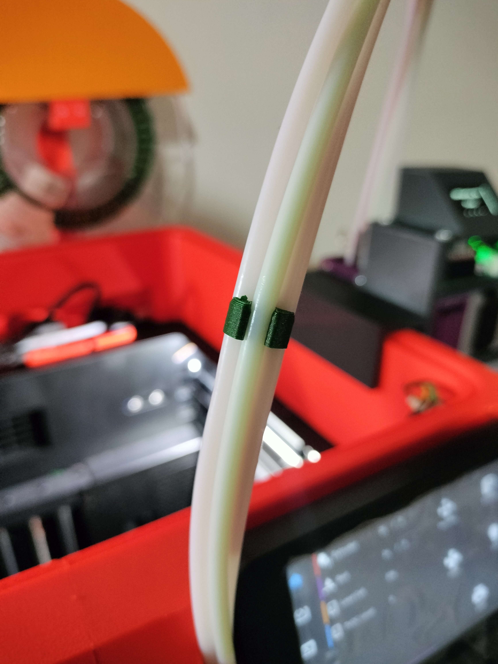
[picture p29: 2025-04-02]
3d chameleon/manual cutter/img/IMG20250402203644.jpg

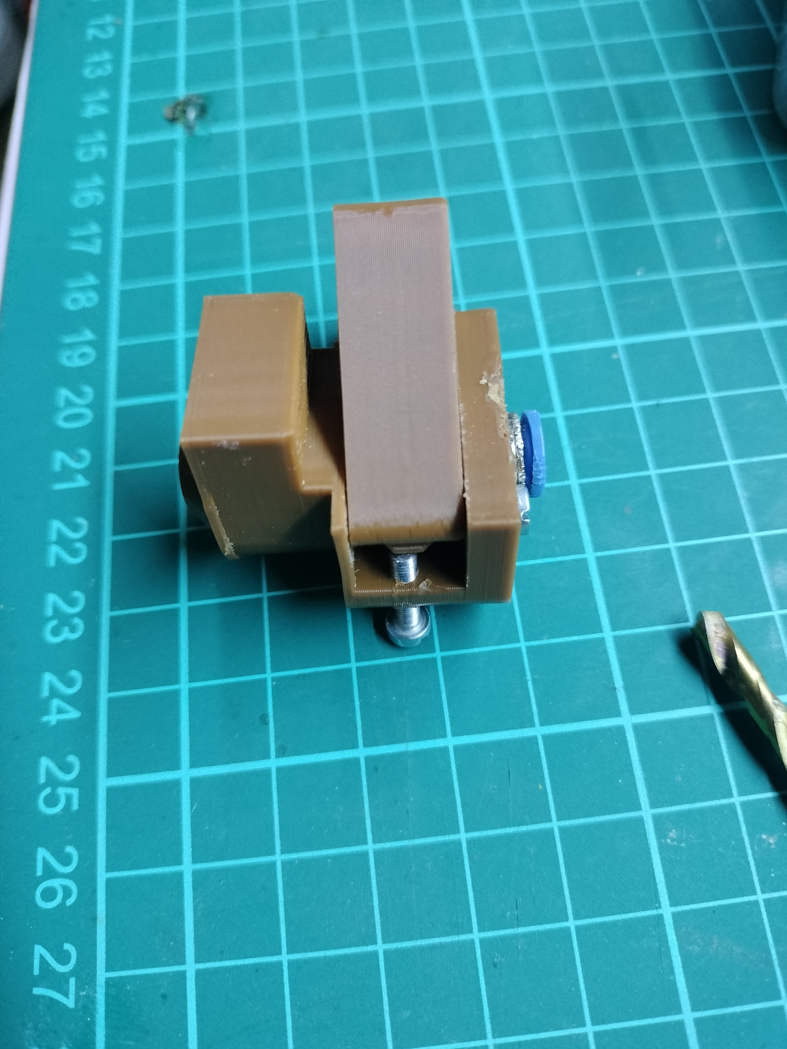
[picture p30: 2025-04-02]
3d chameleon/manual cutter/img/IMG20250402203312.jpg

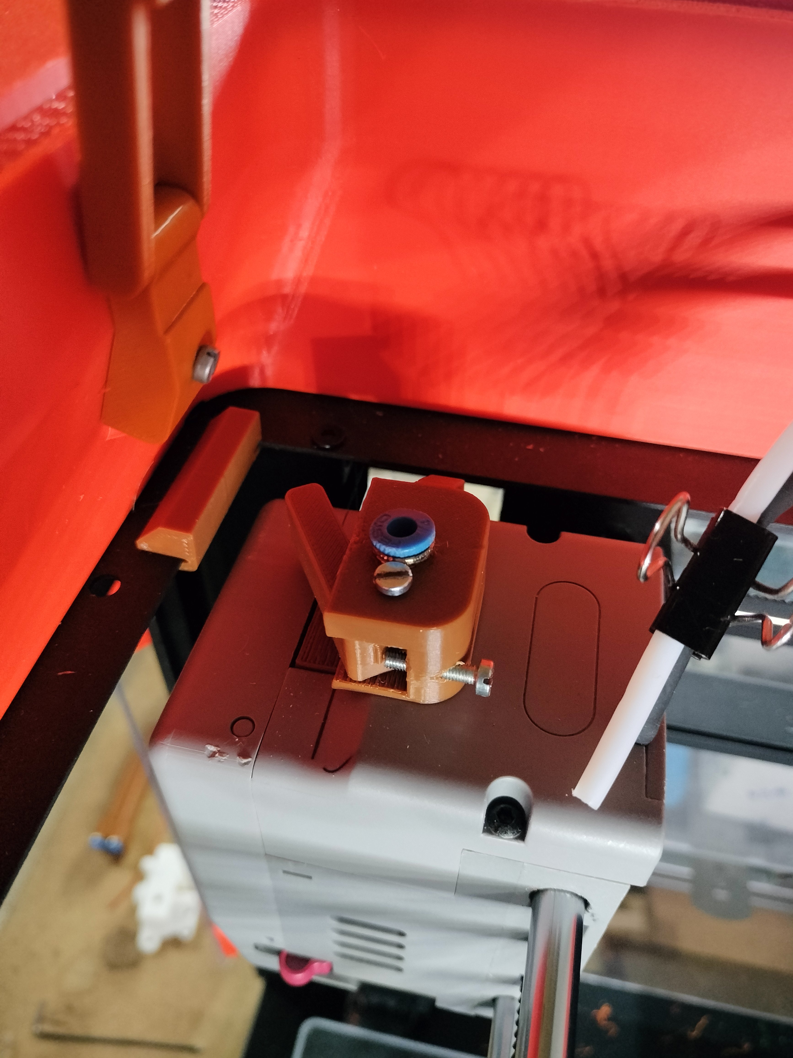
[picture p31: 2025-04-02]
3d chameleon/manual cutter/img/IMG20250402203535.jpg

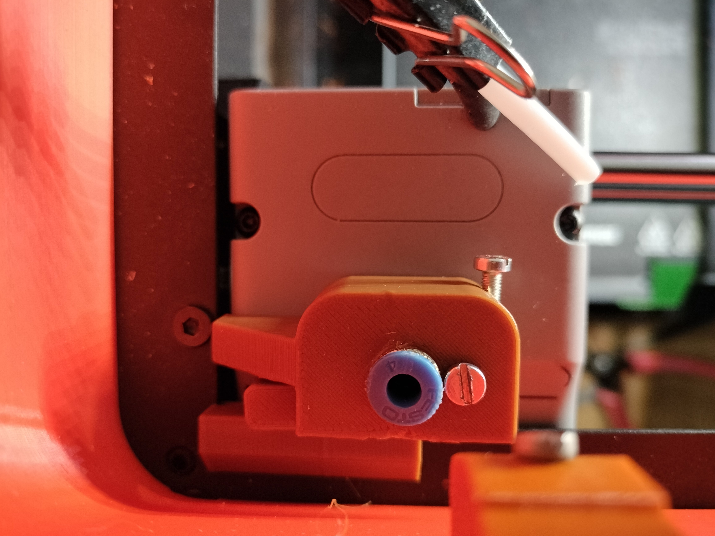
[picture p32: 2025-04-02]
3d chameleon/manual cutter/img/IMG20250402203550.jpg

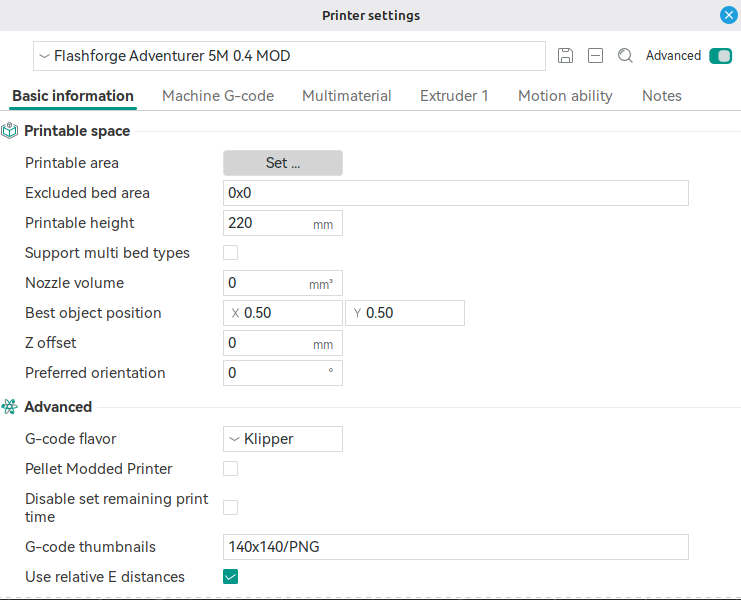
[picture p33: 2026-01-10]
change origin of buildplate/img/orca_orgin1.png

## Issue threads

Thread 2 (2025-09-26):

Start2.gcode does not maintain nozzle and bed temperature throughout bed leveling sequence.

ph0x19, 2025-09-26:
It preheated to the correct temps but maintained temp for PLA, not the ABS temps it was set for. It also spat out a line of ABS then stamped it to the nozzle, and then leveled the bed like that, but that might have been a one-off, I did not try again.

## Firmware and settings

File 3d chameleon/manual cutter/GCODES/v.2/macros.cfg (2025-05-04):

[gcode_macro _CANCEL_PRINT_WITH_AUDIO_WARNING]
gcode:
    G90
    G0 Y-90 X-100 F6000 
    G0 Y-105 X-100 F1800
    G0 Y0 X-100 F2400
    G0 Y0 X-110 F2400 ;stlacenie tlacidla
    G4 P3000  ;caka 6 pulzov pre strih filamentu
    G0 Y0 X-100 F2400 ;presun k tlacidlu
    G4 P2000
    G0 Y0 X-110 F2400 ;stlacenie tlacidla  
    G4 P2500  ;dlzka vysuvania
    G0 Y0 X-100 F2400 ;presun k tlacidlu
    M300 S116 P350
    M300 S61 P1000
    _COMMON_END_PRINT

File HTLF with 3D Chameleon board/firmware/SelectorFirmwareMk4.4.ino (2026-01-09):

// November 28, 2024

/* 3DChameleon Mk4.1 Firmware

Copyright 2024 William J. Steele

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
Single Button Press Commands (count pulses of selector)

#1 - 1
#2 - 2
#3 - 3
#4 - 4
#5 - Home and Load
#6 - Unload Last and Home
#7 - Home
#8 - Next Filament
#9 - Random Filament
 
*/

//#include <SSD1306Ascii.h> //i2C OLED
//#include <SSD1306AsciiWire.h> //i2C OLED
//#include <SparkFunSX1509.h> // sparkfun i/o expansion board - used for additional filament sensors as well as communications with secondary boards
#include <Wire.h>
#include <SPI.h>
#include <Servo.h>
#include <PololuLedStrip.h>


// Create an ledStrip object and specify the pin it will use.
PololuLedStrip<A4> ledStrip;

// Create a buffer for holding the colors (3 bytes per color).
#define LED_COUNT 4
rgb_color colors[LED_COUNT];


// defines pins numbers - 3D Chameleon Board
#define extEnable 0
#define extStep 1
#define extDir 2

#define selEnable A0
#define selStep A1
#define selDir A2

#define trigger A3
#define homestop A5


const int counterclockwise = HIGH;
const int clockwise = !counterclockwise;

const int stepsPerRev = 200;  //200*16 = 1rev = 5.75mm
const int microSteps = 16;

const int speedDelaySelector = 45; //delay for selector 60
const int fastSpeed = 36;  //delay for extruder - 24us=feedrate 2245, 30us = feedrate 1796, 36us=feedrate 1496, 45us=feedrate 1197

//const int defaultBackoff = 20; //30;


Servo filamentCutter;  // create servo object to control a servo
int cutterPos = 0;    // variable to store the servo position
bool reverseServo = true;

int currentExtruder = -1;
//int nextExtruder = 0;
int lastExtruder = -1;
//int tempExtruder = -1;

int seenCommand = 0;
int prevCommand = 0;


long triggerTime = 300;
long pulseTime = (triggerTime / 2);

long pos=12800;


byte value;

long idleCount = 0;

bool T0Loaded = false;
bool T1Loaded = false;
bool T2Loaded = false;
bool T3Loaded = false;

bool homed=false;


void setup()
{

  // wait for it to start up
  delay(50);
    
  
  for(uint16_t x = 0; x < LED_COUNT; x++){
  colors[x] = rgb_color(0, 255, 0);
  ledStrip.write(colors, LED_COUNT);
  delay(200);
  }
  delay(500);
  for(uint16_t x = 0; x < LED_COUNT; x++){
  colors[x] = rgb_color(0, 0, 0);
  ledStrip.write(colors, LED_COUNT);
  delay(200);
  }
   
  seenCommand = 0;

  // Sets the two pins as Outputs
  pinMode(extEnable, OUTPUT);
  pinMode(extStep, OUTPUT);
  pinMode(extDir, OUTPUT);

  pinMode(selEnable, OUTPUT);
  pinMode(selStep, OUTPUT);
  pinMode(selDir, OUTPUT);

  // set up the button
  pinMode(trigger, INPUT_PULLUP);  // selector
  pinMode(homestop, INPUT_PULLUP);  // home endstop
  
  // lock the selector by energizing it
  digitalWrite(selEnable, HIGH);

  // make sure filament isn't blocked by gillotine
  connectGillotine();
  cutFilament();
  disconnectGillotine();
  
  prevCommand = 0;
  homeSelector();
  rotateSelector(9600);//parking position
      
}

int lastLoop = 0;

void loop()
{
  static uint32_t lastTime = 0;

  
  seenCommand = 0;
  idleCount++;
if(homed==false){
    colors[0] = rgb_color(255, 0, 0);
    colors[1] = rgb_color(255, 0, 0);
    colors[2] = rgb_color(255, 0, 0);
    colors[3] = rgb_color(255, 0, 0);
    ledStrip.write(colors, LED_COUNT);
}

  // process button press
  if (digitalRead(trigger) == 0)
  {
    idleCount = 0;
//    logoActive = false;
    unsigned long nextPulse;
    unsigned long pulseCount = 0;
    unsigned long commandCount = 0;

    // keep counting (and pulsing) until button is released
    while (digitalRead(trigger) == 0)
    {
      if(pulseCount<pulseTime)
      {
        pulseCount++;
        displayCommand(pulseCount);
//        if(pulseCount>1) vibrateMotor();
       
        ledStrip.write(colors, LED_COUNT);
       
      }
      delay(400);  // each pulse is 400+ milliseconds apart 
    }
    processCommand(pulseCount); // ok... execute whatever command was caught (by pulse count)
    pulseCount = 0;
  }

  // each loop adds 50ms delay, so that gets added AFTER the command is processed before the next one can start
  delay(50);
}



// display command for each button pulse
void displayCommand(long commandCount)
{

  switch(commandCount)
  {
  case 2:
    ///////////////////////////////////////////////    Switch to #1
    colors[0] = rgb_color(0, 255, 0);
    colors[1] = rgb_color(0, 0, 0);
    colors[2] = rgb_color(0, 0, 0);
    colors[3] = rgb_color(0, 0, 0);
 
    break;
  case 3:
   ///////////////////////////////////////////////     Switch to #2
    colors[0] = rgb_color(0, 0, 0);
    colors[1] = rgb_color(0, 255, 0);
    colors[2] = rgb_color(0, 0, 0);
    colors[3] = rgb_color(0, 0, 0);
    break;
  case 4:
    ///////////////////////////////////////////////    Switch to #3
    colors[0] = rgb_color(0, 0, 0);
    colors[1] = rgb_color(0, 0, 0);
    colors[2] = rgb_color(0, 255, 0);
    colors[3] = rgb_color(0, 0, 0);
    break;
  case 5:
    //////////////////////////////////////////////    Switch to #4
    colors[0] = rgb_color(0, 0, 0);
    colors[1] = rgb_color(0, 0, 0);
    colors[2] = rgb_color(0, 0, 0);
    colors[3] = rgb_color(0, 255, 0);
    break;
  case 6:
   ///////////////////////////////////////////////     Home
    colors[0] = rgb_color(0, 255, 0);
    colors[1] = rgb_color(0, 255, 0);
    colors[2] = rgb_color(0, 255, 0);
    colors[3] = rgb_color(0, 255, 0);
    break;
 
  case 7:
    ///////////////////////////////////////////////    UNLOAD and park
    colors[0] = rgb_color(255, 0, 0);
    colors[1] = rgb_color(255, 0, 0);
    colors[2] = rgb_color(255, 0, 0);
    colors[3] = rgb_color(255, 0, 0);
    break;

  default:
    ///////////////////////////////////////////////     No Command
    colors[0] = rgb_color(0, 0, 0);
    colors[1] = rgb_color(0, 0, 0);
    colors[2] = rgb_color(0, 0, 0);
    colors[3] = rgb_color(0, 0, 0);
    break;
  }
}

// execute the pulse count command
void processCommand(long commandCount)
{

  // select case for commands
  switch (commandCount)
  {
  case 2: // unload current, switch to #0, load
   ///////////////////////////////////////////////    Selected #1
    currentExtruder = 0;
    processMoves();
   ///////////////////////////////////////////////    Idle #1
     colors[0] = rgb_color(0, 255, 0);
        colors[1] = rgb_color(0, 0, 0);
        colors[2] = rgb_color(0, 0, 0);
        colors[3] = rgb_color(0, 0, 0);
     ledStrip.write(colors, LED_COUNT);
    break;

  case 3: // unload current, switch to #1, load
   ///////////////////////////////////////////////    Selected #2
    currentExtruder = 1;
    processMoves();
   ///////////////////////////////////////////////    Idle #2
    colors[0] = rgb_color(0, 0, 0);
        colors[1] = rgb_color(0, 255, 0);
        colors[2] = rgb_color(0, 0, 0);
        colors[3] = rgb_color(0, 0, 0);
            ledStrip.write(colors, LED_COUNT);
    break;

  case 4: // unload current, switch to #3, load
   ///////////////////////////////////////////////    Selected #3
    currentExtruder = 2;
    processMoves();
   ///////////////////////////////////////////////    Idle #3
    colors[0] = rgb_color(0, 0, 0);
        colors[1] = rgb_color(0, 0, 0);
        colors[2] = rgb_color(0, 255, 0);
        colors[3] = rgb_color(0, 0, 0);
            ledStrip.write(colors, LED_COUNT);
    break;

  case 5: // unload current, switch to #4, load
   ///////////////////////////////////////////////    Selected #4
    currentExtruder = 3;
    processMoves();
   ///////////////////////////////////////////////    Idle #4
colors[0] = rgb_color(0, 0, 0);
        colors[1] = rgb_color(0, 0, 0);
        colors[2] = rgb_color(0, 0, 0);
        colors[3] = rgb_color(0, 255, 0);
            ledStrip.write(colors, LED_COUNT);
    break;

  case 6: //home and reload #1
   ///////////////////////////////////////////////    Homing
    homed=false;
    homeSelector();
 
      rotateSelector(9600);//parking position
      
    break;
    
  case 7: // unload current and park
   ///////////////////////////////////////////////    Cutting
    connectGillotine();
    cutFilament();
    switch(lastExtruder)
    {
      case 0:
   ///////////////////////////////////////////////    Press to unload #1
        colors[0] = rgb_color(255, 0, 0);
        colors[1] = rgb_color(0, 0, 0);
        colors[2] = rgb_color(0, 0, 0);
        colors[3] = rgb_color(0, 0, 0);
    ledStrip.write(colors, LED_COUNT);
   rotateSelector(7467);
        break;
      case 1:
   ///////////////////////////////////////////////    Press to unload #2
    colors[0] = rgb_color(0, 0, 0);
        colors[1] = rgb_color(255, 0, 0);
        colors[2] = rgb_color(0, 0, 0);
        colors[3] = rgb_color(0, 0, 0);
    ledStrip.write(colors, LED_COUNT);
    rotateSelector(4500);
        break;
      case 2:
   ///////////////////////////////////////////////    Press to unload #3
      colors[0] = rgb_color(0, 0, 0);
        colors[1] = rgb_color(0, 0, 0);
        colors[2] = rgb_color(255, 0, 0);
        colors[3] = rgb_color(0, 0, 0);
    ledStrip.write(colors, LED_COUNT);
   rotateSelector(2250);
        break;
      case 3:
   ///////////////////////////////////////////////    Press to unload #4
      colors[0] = rgb_color(0, 0, 0);
        colors[1] = rgb_color(0, 0, 0);
        colors[2] = rgb_color(0, 0, 0);
        colors[3] = rgb_color(255, 0, 0);
    ledStrip.write(colors, LED_COUNT);
   rotateSelector(20);
        break;
    } 
      rotateExtruder(counterclockwise);
      homed=false;
      homeSelector();
      rotateSelector(9600);//parking position
      
    disconnectGillotine();
   ///////////////////////////////////////////////    Idle
    break;

  default:
   ///////////////////////////////////////////////    Clear (no command)
    delay(200);
homed=false;
      homeSelector();
      
      rotateSelector(9600);//parking position
      
   ///////////////////////////////////////////////    Idle
    break;
  }
}



// real work is here
void processMoves()
{

  // make sure we have a real extruder selected
  if(lastExtruder>-1)
  {

    // if so, we need to cut the filament
   ///////////////////////////////////////////////    Cutting
    connectGillotine();
    cutFilament();

    // ok... then wait for the 2nd button press to unload it
    switch(lastExtruder)
    {
      case 0:
   ///////////////////////////////////////////////    Press to unload #1 - switching
        
        colors[0] = rgb_color(255, 0, 0);
        colors[1] = rgb_color(0, 0, 0);
        colors[2] = rgb_color(0, 0, 0);
        colors[3] = rgb_color(0, 0, 0);
            ledStrip.write(colors, LED_COUNT);
         rotateSelector(7467);
        break;
      case 1:
   ///////////////////////////////////////////////    Press to unload #2 - switching
        colors[0] = rgb_color(0, 0, 0);
        colors[1] = rgb_color(255, 0, 0);
        colors[2] = rgb_color(0, 0, 0);
        colors[3] = rgb_color(0, 0, 0);
            ledStrip.write(colors, LED_COUNT);
         rotateSelector(4978);
        break;
      case 2:
   ///////////////////////////////////////////////    Press to unload #3 - switching
        colors[0] = rgb_color(0, 0, 0);
        colors[1] = rgb_color(0, 0, 0);
        colors[2] = rgb_color(255, 0, 0);
        colors[3] = rgb_color(0, 0, 0);
            ledStrip.write(colors, LED_COUNT);
           rotateSelector(2489);
        break;
      case 3:
   ///////////////////////////////////////////////    Press to unload #4 - switching
        colors[0] = rgb_color(0, 0, 0);
        colors[1] = rgb_color(0, 0, 0);
        colors[2] = rgb_color(0, 0, 0);
        colors[3] = rgb_color(255, 0, 0);
      rotateSelector(20);
            ledStrip.write(colors, LED_COUNT);
        break;
    } 


  rotateExtruder(counterclockwise);
  }
  else
  {
    lastExtruder = 0;
  }
  disconnectGillotine();
  
 // ok... filament unloaded, time to load the new... so tell the user
  switch(currentExtruder)
  {
    case 0:
   ///////////////////////////////////////////////    Press to load #1
       colors[0] = rgb_color(255, 102, 0);
        colors[1] = rgb_color(0, 0, 0);
        colors[2] = rgb_color(0, 0, 0);
        colors[3] = rgb_color(0, 0, 0);
            ledStrip.write(colors, LED_COUNT);
      rotateSelector(7467);
      break;
    case 1:
   ///////////////////////////////////////////////    Press to load #2
      colors[0] = rgb_color(0, 0, 0);
        colors[1] = rgb_color(255, 102, 0);
        colors[2] = rgb_color(0, 0, 0);
        colors[3] = rgb_color(0, 0, 0);
            ledStrip.write(colors, LED_COUNT);
      rotateSelector(4500);
      break;
    case 2:
   ///////////////////////////////////////////////    Press to load #3
      colors[0] = rgb_color(0, 0, 0);
        colors[1] = rgb_color(0, 0, 0);
        colors[2] = rgb_color(255, 102, 0);
        colors[3] = rgb_color(0, 0, 0);
            ledStrip.write(colors, LED_COUNT);
            rotateSelector(2250);
      break;
    case 3:
   ///////////////////////////////////////////////    Press to load #4
      colors[0] = rgb_color(0, 0, 0);
        colors[1] = rgb_color(0, 0, 0);
        colors[2] = rgb_color(0, 0, 0);
        colors[3] = rgb_color(255, 102, 0);
            ledStrip.write(colors, LED_COUNT);
            rotateSelector(20);
      break;
  }


  rotateExtruder(clockwise);

delay(500);
rotateSelector(9600);//parkovacia poloha

  
  // everybody remember where we parked!
  lastExtruder = currentExtruder;
}



// move the extruder motor in a specific direction for a specific distance (unless it's a "until button is not pressed")
///void rotateExtruder(bool direction, long moveDistance)
void rotateExtruder(bool direction)

{
  // note to bill:  make this acecelerate so it's very fast!!!
  
  digitalWrite(extEnable, LOW);  // lock the motor
  digitalWrite(extDir, direction); // Enables the motor to move in a particular direction
 // const int fastSpeed = speedDelay/speedFactor; // double time

  // this is depricated right now... might bring it back in the future

   // keep waiting until button is pressed
   while (digitalRead(trigger) != 0)
    {
      delay(50);
    }
    
    // Move while button is pressed
    while (digitalRead(trigger) == 0)
    {

      // this is how we pulse the motor to get it to step
      digitalWrite(extStep, HIGH);
      delayMicroseconds(fastSpeed);
      digitalWrite(extStep, LOW);
      delayMicroseconds(fastSpeed);
    }

  
  // ok, done pressing button, so make sure we're not energized (high is no, low is yes)
  digitalWrite(extEnable, HIGH);
}



// similar to extruder, but only stepping 50 (of 200) at a time
//void rotateSelector(bool direction, long workPos)
void rotateSelector(long workPos)
{

  // while we are at it... can we make this faster using the magic you invented above?
  
  digitalWrite(selEnable, LOW); // lock the selector
///  digitalWrite(selDir, direction); // Enables the motor to move in a particular direction

  while(pos!=workPos){
      if(workPos>pos){digitalWrite(selDir, 1); pos++;}
      if(workPos<pos){digitalWrite(selDir, 0); pos--;}
     
      digitalWrite(selStep, HIGH);
      delayMicroseconds(speedDelaySelector);
      digitalWrite(selStep, LOW);
      delayMicroseconds(speedDelaySelector);
      
      if(pos==workPos)break;
   
  }
  ///  digitalWrite(selEnable, HIGH);
}


// rotate the selector clockwise too far from 4, so it'll grind on the bump stop
void homeSelector()
{
    digitalWrite(selEnable, LOW); // lock the selector
    digitalWrite(selDir, 0);
    
 while (digitalRead(homestop) != 0)  //ak nie je koncak zopnuty
  {
      digitalWrite(selStep, HIGH);
      delayMicroseconds(speedDelaySelector);
      digitalWrite(selStep, LOW);
      delayMicroseconds(speedDelaySelector);
  
    if(digitalRead(homestop)==0)break;
    
    }
  
  // move just slightly to extruder 1 (this backs off a little from the hard stop)

 currentExtruder = 0;
 lastExtruder = -2;
 
    colors[0] = rgb_color(0, 0, 0);
    colors[1] = rgb_color(0, 0, 0);
    colors[2] = rgb_color(0, 0, 0);
    colors[3] = rgb_color(0, 0, 0);
   ledStrip.write(colors, LED_COUNT);
delay(500);

    colors[0] = rgb_color(0, 255, 0);
    colors[1] = rgb_color(0, 255, 0);
    colors[2] = rgb_color(0, 255, 0);
    colors[3] = rgb_color(0, 255, 0);
   ledStrip.write(colors, LED_COUNT);
 delay(500);
    colors[0] = rgb_color(0, 0, 0);
    colors[1] = rgb_color(0, 0, 0);
    colors[2] = rgb_color(0, 0, 0);
    colors[3] = rgb_color(0, 0, 0);
   ledStrip.write(colors, LED_COUNT);
     
   homed=true;
   pos=0;
}




/////////////////////////////////////////////////////////////////////////////
//
// GILOTINE
//
////////////////////////////////////////////////////////////////////////////
// this cycles the servo between two positions
void cutFilament() {
  digitalWrite(selEnable, LOW); // disable stepper so we have power!
  if(reverseServo==false)
  {
    openGillotine();
    closeGillotine();
  }
  else
  {
    closeGillotine();
    openGillotine();
  }
  digitalWrite(selEnable, HIGH);
}



// enable the servo
void connectGillotine()
{
  filamentCutter.attach(11);
}



// disable the servo - so it doesn't chatter when not in use
void disconnectGillotine()
{
  filamentCutter.detach();
}



// cycle servo from 135 and 180
void openGillotine()
{
    for (int pos = 125; pos <= 195; pos += 1) { // goes from 0 degrees to 180 degrees
    // in steps of 1 degree
    filamentCutter.write(pos);              // tell servo to go to position in variable 'pos'
    delayMicroseconds(25000);                       // waits 15ms for the servo to reach the position
  }
  //filamentCutter.write(3.5);       // tell servo to go to position in variable 'pos'
  delay(50);                       // waits 15ms for the servo to reach the position
}



// reverse cycle servo from 180 back to 135
void closeGillotine()
{
  for (int pos = 195; pos >= 125; pos -= 1) { // goes from 180 degrees to 0 degrees
    filamentCutter.write(pos);              // tell servo to go to position in variable 'pos'
    delayMicroseconds(25000);                       // waits 15ms for the servo to reach the position
  }
  delay(50);                       // waits 15ms for the servo to reach the position
}

// buzz buzz buzz
/*
void vibrateMotor()
{
  // oscillate selector 1 time
 /// rotateSelector(clockwise, 8);
 /// rotateSelector(!clockwise, 8);
 rotateSelector(pos+1);
 rotateSelector(pos-1);
}
*/

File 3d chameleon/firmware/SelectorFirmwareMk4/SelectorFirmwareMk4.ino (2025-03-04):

// November 28, 2024

/* 3DChameleon Mk4.1 Firmware

Copyright 2024 William J. Steele

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
Single Button Press Commands (count pulses of selector)

#1 - 1
#2 - 2
#3 - 3
#4 - 4
#5 - Home and Load
#6 - Unload Last and Home
#7 - Home
#8 - Next Filament
#9 - Random Filament
 
*/

#include <SSD1306Ascii.h> //i2C OLED
#include <SSD1306AsciiWire.h> //i2C OLED
#include <SparkFunSX1509.h> // sparkfun i/o expansion board - used for additional filament sensors as well as communications with secondary boards
#include <Wire.h>
#include <SPI.h>
#include <Servo.h>


#define SCREEN_WIDTH 128 // OLED display width, in pixels
#define SCREEN_HEIGHT 64 // OLED display height, in pixels

/**
 * Made with Marlin Bitmap Converter
 * https://marlinfw.org/tools/u8glib/converter.html
 *
 * This bitmap from 128x64 pasted image
 */
#pragma once

const unsigned char bitmap_logo[] PROGMEM = {
  B00000000,B00000000,B00000000,B00000000,B00000000,B00000000,B00000000,B00000000,B00000000,B00000000,B00000000,B00000000,B00000000,B00000000,B00000000,B00000000,
  B00000000,B00000000,B00000000,B00000000,B00000000,B00000000,B00000000,B00000000,B00000000,B00000000,B00000000,B00000000,B00000000,B00000000,B00000000,B00000000,
  B00000000,B00000000,B00000000,B00000000,B00000000,B00000000,B00000000,B00000000,B00000000,B00000000,B00000000,B00000000,B00000000,B00000000,B00000000,B00000000,
  B00000000,B00000000,B00000000,B00000000,B00000000,B00000000,B00000000,B00000000,B00000000,B00000000,B00000000,B00000000,B00000000,B00000000,B00000000,B00000000,
  B00000000,B00000000,B00000000,B00000000,B00000000,B00000000,B00000000,B00001000,B00000000,B00000000,B00000000,B00000000,B00000000,B00000000,B00000000,B00000000,
  B00000000,B00000000,B00000000,B00000000,B00000000,B00000000,B00110000,B00001100,B00100000,B00000000,B00000000,B00000000,B00000000,B00000000,B00000000,B00000000,
  B00000000,B00000000,B00000000,B00000000,B00000000,B00000000,B01111100,B00001110,B00110000,B00011100,B00000000,B00000000,B00000000,B00000000,B00000000,B00000000,
  B00000000,B00000000,B00000000,B00000000,B00000000,B00000000,B01111111,B00011111,B01111000,B00011111,B00000000,B00000000,B00000000,B00000000,B00000000,B00000000,
  B00000000,B00000000,B00000000,B00000000,B00000000,B00000000,B01111111,B10011111,B11111000,B00011111,B10000000,B00000000,B00000000,B00000000,B00000000,B00000000,
  B00000000,B00000000,B00000000,B00000000,B00000000,B00000000,B01111111,B11011111,B11110110,B00011111,B11000000,B00000000,B00000000,B00000000,B00000000,B00000000,
  B00000000,B00000000,B00000000,B00000000,B00000000,B00000000,B01111111,B10000000,B00000110,B00011111,B11100000,B00000000,B00000000,B00000000,B00000000,B00000000,
  B00000000,B00000000,B00000000,B00000000,B00000000,B11111100,B01111101,B11111111,B11110010,B00111111,B11110000,B00000000,B00000000,B00000000,B00000000,B00000000,
  B00000000,B00000000,B00000000,B00000000,B00000000,B11111111,B00001111,B11111111,B11111110,B00111111,B11111000,B00000000,B00000000,B00000000,B00000000,B00000000,
  B00000000,B00000000,B00000000,B00000000,B00000000,B01111111,B00111111,B11111111,B11111111,B00111111,B11111100,B00000000,B00000000,B00000000,B00000000,B00000000,
  B00000000,B00000000,B00000000,B00000000,B00000000,B01111110,B00111111,B11111111,B11111111,B01111111,B11111100,B00000000,B00000000,B00000000,B00000000,B00000000,
  B00000000,B00000000,B00000000,B00000000,B00000000,B01111101,B11111111,B11111111,B11111111,B01111111,B11111110,B00000000,B00000000,B00000000,B00000000,B00000000,
  B00000000,B00000000,B00000000,B00000000,B00000000,B01111011,B11111111,B11111111,B11111110,B11111111,B11111110,B00000000,B00000000,B00000000,B00000000,B00000000,
  B00000000,B00000000,B00000000,B00000000,B00000000,B01100111,B11101111,B11111111,B11111111,B11111111,B11111110,B00000000,B00000000,B00000000,B00000000,B00000000,
  B00000000,B00000000,B00000000,B00000000,B00000111,B10001111,B11110111,B11111111,B11111111,B11111111,B11111111,B00000000,B00000000,B00000000,B00000000,B00000000,
  B00000000,B00000000,B00000000,B00000000,B00001111,B10111111,B11111011,B11111111,B11111101,B11111110,B00011111,B00000000,B00000000,B00000000,B00000000,B00000000,
  B00000000,B00000000,B00000000,B00000000,B00001111,B10111111,B11111001,B11111111,B11111111,B11111100,B00001111,B00000000,B00000000,B00000000,B00000000,B00000000,
  B00000000,B00000000,B00000000,B00000000,B00001111,B01111111,B11111101,B11111111,B11111111,B11111001,B11110111,B00000000,B00000000,B00000000,B00000000,B00000000,
  B00000000,B00000000,B00000000,B00000000,B00000111,B11111111,B11111110,B11111111,B11111111,B11111011,B11110011,B00000000,B00000000,B00000000,B00000000,B00000000,
  B00000000,B00000000,B00000000,B00000000,B00000010,B11111111,B11111110,B11111111,B11111111,B11111011,B10111011,B00000000,B00000000,B00000000,B00000000,B00000000,
  B00000000,B00000000,B00000000,B00000000,B00111100,B11111111,B11111111,B01111111,B11111111,B11111011,B11110011,B00000000,B00000000,B00000000,B00000000,B00000000,
  B00000000,B00000000,B00000000,B00000000,B01111101,B11111111,B11111111,B01111111,B11111111,B11111001,B11110111,B00000000,B00000000,B00000000,B00000000,B00000000,
  B00000000,B00000000,B00000000,B00000000,B01111101,B11111111,B11111111,B10111111,B11111101,B11111100,B11101111,B00000000,B00000000,B00000000,B00000000,B00000000,
  B00000000,B00000000,B00000000,B00000000,B00111101,B11111111,B11111111,B10000000,B00000000,B11111111,B11011111,B00000000,B00000000,B00000000,B00000000,B00000000,
  B00000000,B00000000,B00000000,B00000000,B00011001,B11111111,B11111111,B10000000,B00000000,B11111111,B11111111,B00000000,B00000000,B00000000,B00000000,B00000000,
  B00000000,B00000000,B00000000,B00000000,B00001011,B11111111,B11111111,B01100000,B00000000,B01111111,B11111111,B00000000,B00000000,B00000000,B00000000,B00000000,
  B00000000,B00000000,B00000000,B00000000,B00000001,B11111111,B11111110,B11111000,B00000000,B00111111,B11111111,B00000000,B00000000,B00000000,B00000000,B00000000,
  B00000000,B00000000,B00000000,B00000000,B00011010,B01111111,B11111101,B11111110,B00000000,B00001111,B11111110,B00000000,B00000000,B00000000,B00000000,B00000000,
  B00000000,B00000000,B00000000,B00000000,B01111011,B11100111,B11111011,B11111110,B00000000,B00000111,B11111110,B00000000,B00000000,B00000000,B00000000,B00000000,
  B00000000,B00000000,B00000000,B00000000,B11111011,B11111100,B01110000,B01111111,B00000000,B00000001,B11111110,B00000000,B00000000,B00000000,B00000000,B00000000,
  B00000000,B00000000,B00000000,B00000000,B01111011,B11111111,B00000000,B01111111,B10000000,B00000000,B01111100,B00000000,B00000000,B00000000,B00000000,B00000000,
  B00000000,B00000000,B00000000,B00000000,B00011011,B11111111,B11000000,B11111111,B11111000,B00000000,B00000000,B00000000,B00000000,B00000000,B00000000,B00000000,
  B00000000,B00000000,B00000000,B00000000,B00001011,B11111111,B11100001,B11111111,B11111110,B00000000,B00000000,B00000000,B00000000,B00000000,B00000000,B00000000,
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

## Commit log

2024-02-24 Rename IMG_20240224_131420.jpg to usb camera/IMG_20240224_131420.jpg
2025-03-13 Update START-01
    add part for cleaning nozzle before leveling, add part for auto loading filament if in slicer was selected different color
2025-04-01 Rename 3d chameleon/Gcodes/CHANGE-01 to 3d chameleon/with servo cutter/GCODES/CHANGE-01
    moved
2025-04-01 Rename 3d chameleon/Gcodes/END-01 to 3d chameleon/with servo cutter/GCODES/END-01
    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
2025-04-01 Rename 3d chameleon/Gcodes/START-01 to 3d chameleon/with servo cutter/Gcodes/START-01
2025-04-01 Rename 3d chameleon/STL/ad5m-v5-4in1.stl to 3d chameleon/with servo cutter/STL/ad5m-v5-4in1.stl
    [ad5m-v5-4in1.stl]
2025-04-01 Rename 3d chameleon/STL/chameleon-drziak.stl to 3d chameleon/with servo cutter/STL/chameleon-drziak.stl
    [chameleon-drziak.stl]
2025-04-01 Rename 3d chameleon/with servo cutter/STL/chameleon-drziak.stl to 3d chameleon/STL/chameleon-drziak.stl
    [chameleon-drziak.stl]
2025-04-01 Rename 3d chameleon/STL/clipy-ad5m-body.stl to 3d chameleon/with servo cutter/STL/clipy-ad5m-body.stl
    [clipy-ad5m-body.stl]
2025-04-01 Rename 3d chameleon/ad5m cut - arm - long.stl to 3d chameleon/manual cutter/STL/ad5m cut - arm - long.stl
    [ad5m cut - arm - long.stl]
2025-04-02 Rename 3d chameleon/STL/ad5m 4n1 - body.stl to 3d chameleon/manual cutter/STL/ad5m 4n1 - body.stl
    [ad5m 4n1 - body.stl]
